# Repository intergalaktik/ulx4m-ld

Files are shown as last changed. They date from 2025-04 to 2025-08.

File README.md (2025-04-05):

# ULX4M-LD PCB

[ULX4M] = University digital Logic Learning Xtensible board release 4 Moduler successor of [ULX3S](http://radiona.org/ulx3s) = [University digital Logic](https://www.fer.unizg.hr/en/course/diglog) Learning
Xtensible board release 3 with SDRAM,
Successor of [ULX2S](http://github.com/emard/ulx2s).

3D preview

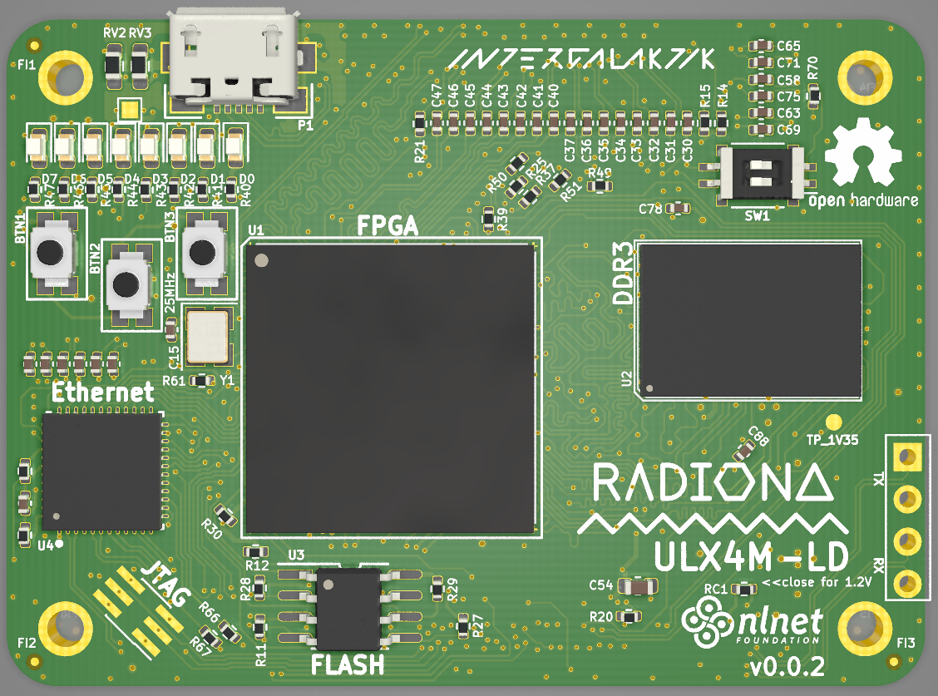
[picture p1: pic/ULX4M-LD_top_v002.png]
TOP

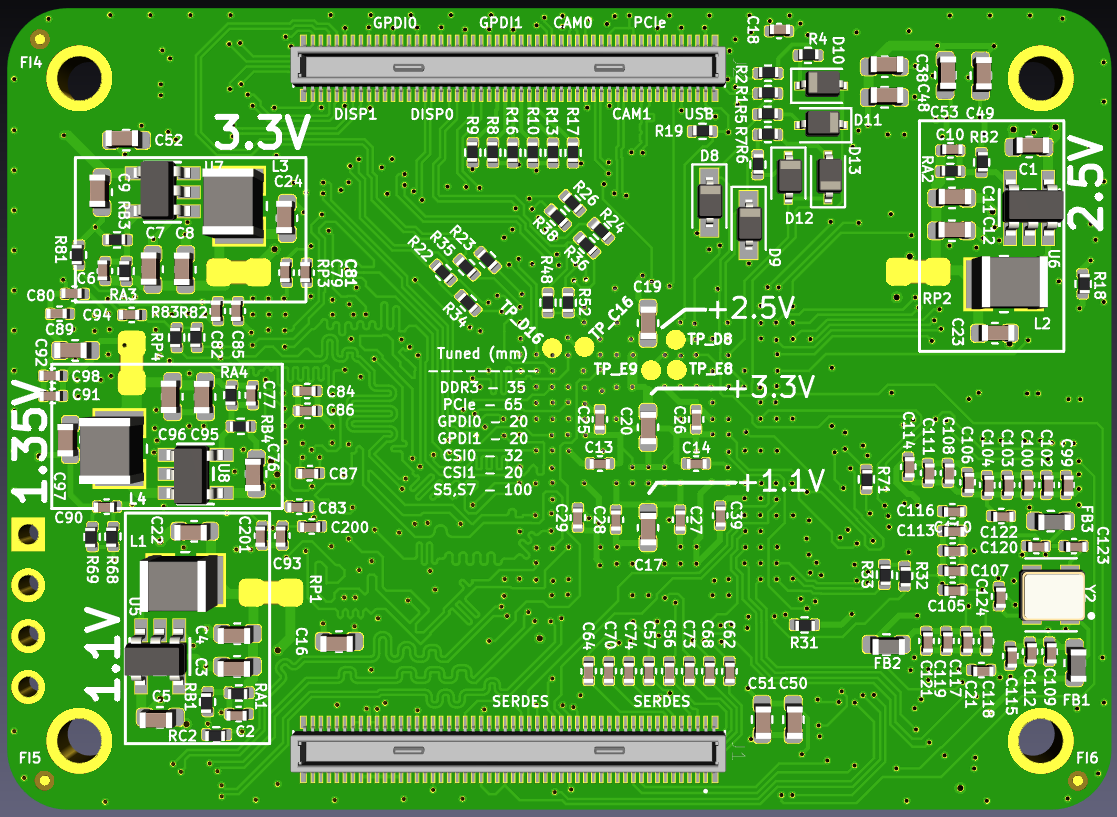
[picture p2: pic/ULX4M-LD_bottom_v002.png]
BOTTOM

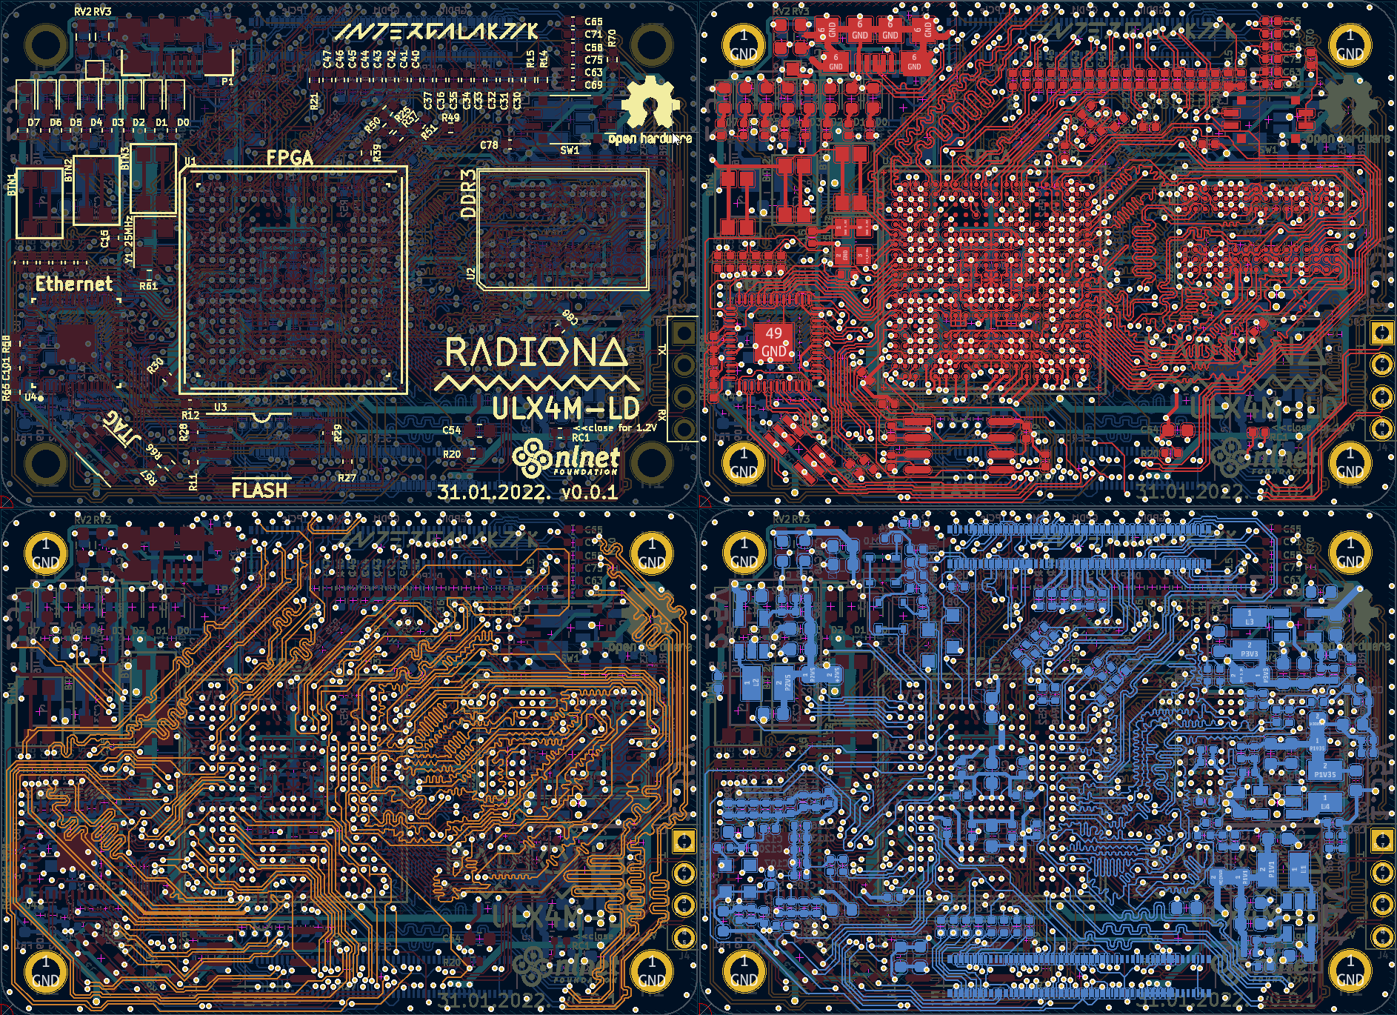
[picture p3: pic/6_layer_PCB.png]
Layers_v001


### Panel

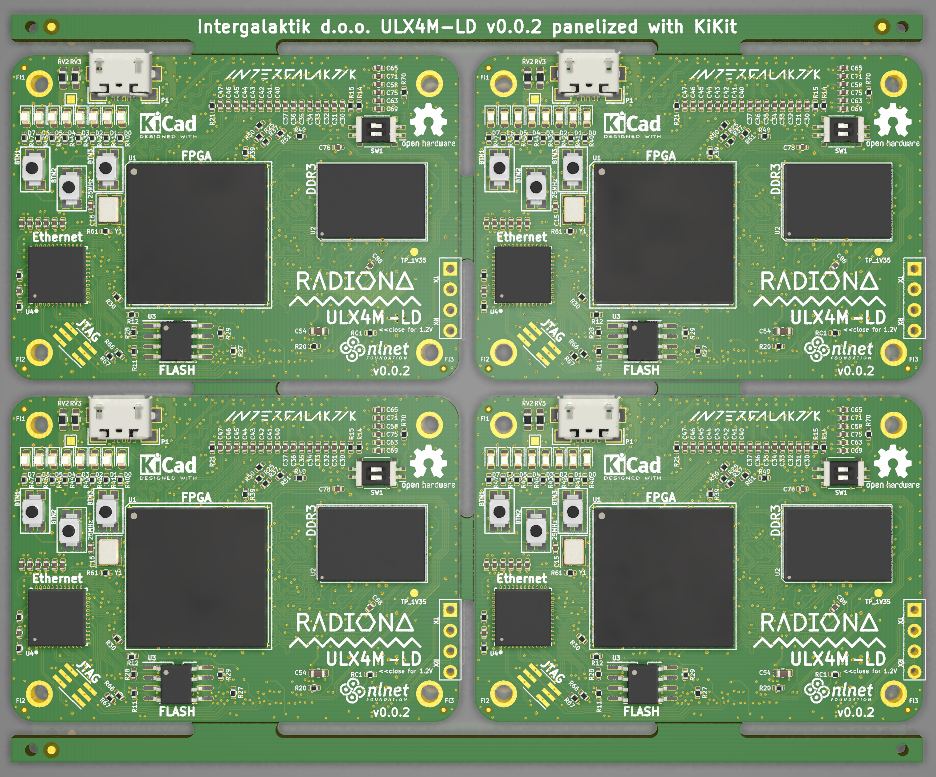
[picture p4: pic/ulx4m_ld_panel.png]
Panel


[Schematics](/doc/schematics.pdf) and PCB KiCAD 5 PCB editor:

    kicad ulx4m.pro

# Features

FPGA: Lattice ECP5 [LFE5U-85F-6BG381C](http://www.latticesemi.com/~/media/LatticeSemi/Documents/DataSheets/ECP5/FPGA-DS-02012.pdf?document_id=50461) (12/25/45/85K LUT)

### Main parts

LFE5UM-85F-8BG381C

MT41K256M16TW-107 512MB DDR3

W25Q128JVSIM NOR Flash spiFlash, 3V, 128M-bit, 4Kb Uniform Sector

Ethernet - KSZ9031RNXCA

### Programming options

External JTAG programming connector

JTAG connected to GPIO (programming with FTDI or ESP32)

USB (bootloader)

### Periferals

- [x] 2 lane CSI camera port  CAM0 and CAM1

- [x] 2 lane DSI display port DISP0 (fake differential)

- [x] SerDes pair connected to second DSI connector DISP1

- [x] SerDes pair (TX/RX) connected to 2.0 header (radio experiments)

- [x] True differential GPDI video output

- [x] Fake differential GPDI video output

- [x] SD card connection - shared with HAT pins

- [x] SerDes connected to PCIe 1x 

- [x] 2x SerDes pairs connected over capacitors to connector

- [x] GPIOs

- [x] 3 Buttons

- [x] 2 DIP SW

- [x] 8 LEDs

## References

https://github.com/gatecat/TrellisBoard

https://github.com/orangecrab-fpga/orangecrab-hardware

https://github.com/antmicro/ecp5-dc-scm

https://github.com/butterstick-fpga/butterstick-hardware

## Work on this board is financed by NLnet foundation

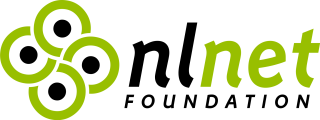
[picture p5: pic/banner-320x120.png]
NLnet


https://nlnet.nl/project/ULX3M/

## Check up our blogposts

https://intergalaktik.eu/news/ulx4s-v0-0-1

https://intergalaktik.eu/news/ulx4s-v0-0-2

https://intergalaktik.eu/news/blending-ulx4m-nlnet-funded-fpga-board

https://intergalaktik.eu/news/production-testing-automation-for-ulx3s

https://intergalaktik.eu/news/blending-ulx4m-ls-v002

## Contact us

Discord: https://discord.gg/qwMUk6W

Gitter: https://gitter.im/ulx3s/Lobby

Mail: warp@intergalaktik.eu

Twitter: https://twitter.com/intergalaktikEU

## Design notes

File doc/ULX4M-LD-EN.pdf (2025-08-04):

MANUAL FOR THE USE OF MODULAR TILES

# ULX4M-LD

1

SADRŽAJ

ULX4M-LD (Lattice+DDR3)

### 1. Introduction 1.1. Main parts 1.2. Programing options 1.3. Periferije 1.4. Electrical and mechanical specifications 1.5. Pinout 1.6. Power 2. ULX4M-LD description and instructions 3. ULX4M-LD on the internet 3.1. ULX4M-LD design files 3.2. ULX4M-LD v2 schematics

### 3.3. ULX4M-LD v2 LPF

### 3.4. ULX4M pohrana 4. JTAG over GPIO 5. DFU bootloader for ULX4M 5.1. Usage 5.2. Write Protecting Bootloader 6. Chat and support 6.1. Instructions for safe use

2

# ULX4M-LD (Lattice+DDR3)

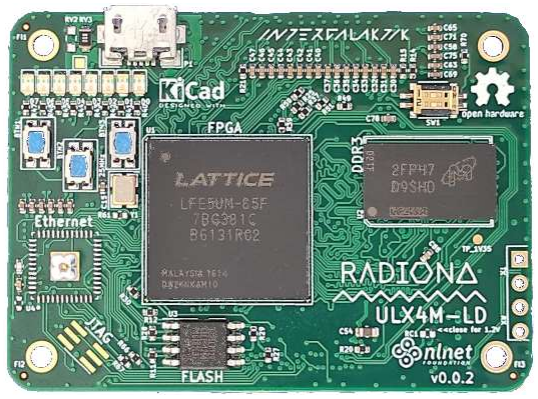
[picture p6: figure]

Slika 1. ULX4M-LD modular plate

FPGA: Lattice ECP5 LFE5U-85F-6BG381C (12/25/45/85K LUT)

3

# 1.Introduction

ULX4M-LD (Lattice + DDR3) is a system on a module (SoM) board that can be used on CM4 compatible base boards or as a standalone board.

## 1.1. Main parts

- LFE5UM-85F-8BG381C
- MT41K256M16TW-107 512MB DDR3
- W25Q128JVSIM NOR Flash spiFlash, 3V, 128M-bit, 4Kb Uniform Sector
- Ethernet – KSZ9031RNXCA

## 1.2. Programing options

External JTAG programming connector

JTAG connected to GPIO (programming with FTDI or ESP32)

USB (bootloader)

## 1.3. Periferije

- 2 lane CSI camera port CAM0 and CAM1
- 2 lane DSI display port DISP0 (fake differential)
- SerDes pair connected to second DSI connector DISP1
- SerDes pair (TX/RX) connected to 2.0 header (radio experiments)
- True differential GPDI video output
- Fake differential GPDI video output

4

- SD card connection - shared with HAT pins
- SerDes connected to PCIe 1x
- 2x SerDes pairs connected over capacitors to connector
- GPIOs
- 3 Buttons
- 2 DIP SW
- 8 LEDs

## 1.4. Electrical and mechanical specifications

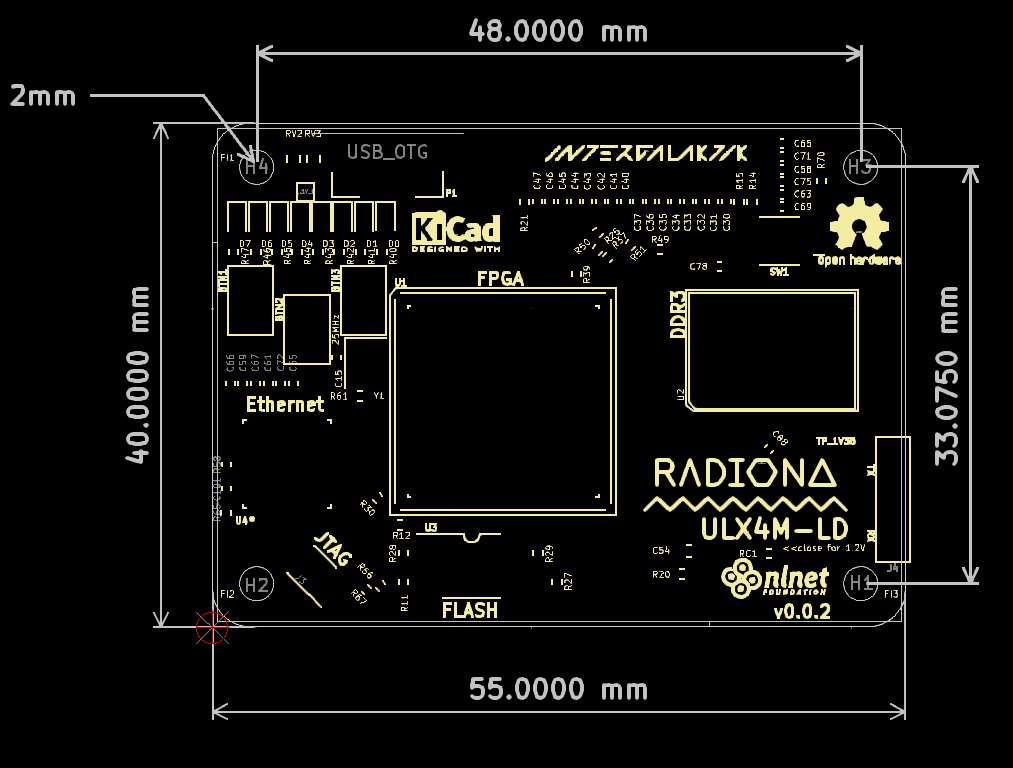
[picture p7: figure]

Slika 2. Electrical and mechanical specifications

5

## 1.5. Pinout

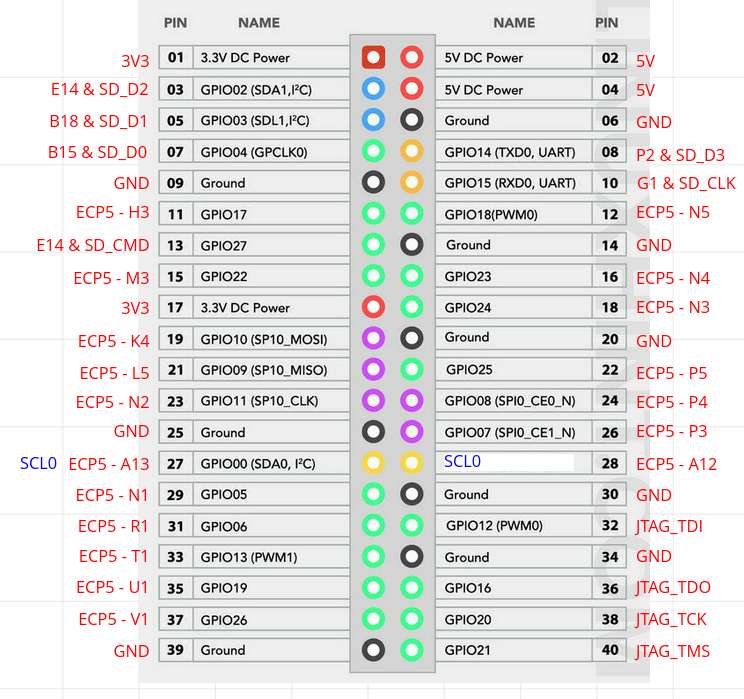
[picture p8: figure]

Slika 3. Input/output pins

## 1.6. Power

ULX4M requires at least 500mA to function safely. A 5V power supply can be provided over a USB port or over GPIO. 3.3V OUTPUT from ULX3S can handle up to 1A if appropriate input power is used.

6

# 2.ULX4M-LD description and instructions

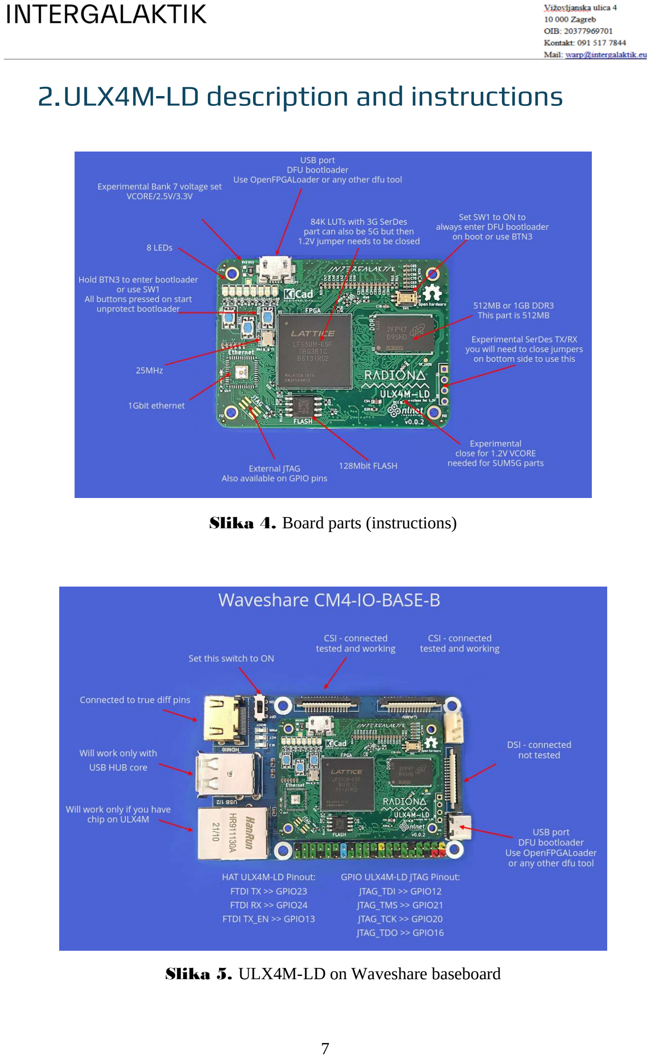
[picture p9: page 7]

Slika 4. Board parts (instructions)

Slika 5. ULX4M-LD on Waveshare baseboard

7

On this version SD_CARD is also connected to GPIO pins, so we can share it with ESP32 as on ULX3S.

On this version FPGA JTAG pins are connected to some GPIO pins so you will not be able to use them as GPIOs, but you can access JTAG over GPIO.

If a Waveshare IO board is used it can be powered from USB-C.

If you are using a Raspberry IO board then you will need 12V DC input as micro USB does not have 5V connected. There is one wire hack that can provide 5V from USB to the board. If this hack is used USB HOST will not work as it will disable HUB chip.

8

# 3.ULX4M-LD on the internet

## 3.1. ULX4M-LD design files

https://github.com/intergalaktik/ulx4m/tree/ulx4m-ls

## 3.2. ULX4M-LD v2 schematics

https://github.com/intergalaktik/ulx4m/blob/ulx4m-ld/doc/schematics.pdf

## 3.3. ULX4M-LD v2 LPF

https://github.com/intergalaktik/ulx4m/blob/ulx4m-ls/doc/constraints/prototype/ulx4m-ld_v002.lpf

## 3.4. ULX4M examples

https://github.com/lawrie/ulx4m_examples

https://github.com/lawrie/ulx4m_amaranth_examples

https://github.com/emard/ulx3s-misc

https://github.com/emard/had2019-playground/tree/master/projects/bootloader

https://github.com/goran-mahovlic/mipi-csi-2

https://github.com/hdl4fpga/hdl4fpga

9

# 4.DFU bootloader for ULX4M

USB DFU at US1 port for FPGA flashing. DFU is very fast.

Source is based on HAD2019 badge bootloader modified to ULX3S bootloader

Bootloader by default skips to the user's bitstream. If FLASH doesn't contain a valid user's bitstream, LEDs will blink because the bootloader is constantly restarting. This is normal.

To enter bootloader, hold BTN2 or set DIP SW1=ON and plug US1 In bootloader mode, LEDs 0-2 should be ON, other LEDs 3-7 OFF:

lsusb

Bus 001 Device 117: ID 1d50:614b OpenMoko, Inc. ULX4M-LD(DFU)

On linux, it's practical to add a udev rule which allows normal users members of "dialout" group to also run dfu-util, otherwise it should be run as root:

# file: /etc/udev/rules.d/80-fpga-dfu.rules

# this is for DFU 1d50:614b libusb access

ATTRS{idVendor}=="1d50", ATTRS{idProduct}=="614b", \

GROUP="dialout", MODE="666"

DFU is very fast, writes bitstreams in a few seconds.

## 4.1. Usage

To upload a user bitstream, hold BTN2 or turn on DIP SW1 and plug USB. Here are some commandline examples:

openFPGALoader -b ulx3s-dfu blink.bit

or

dfu-util -a 0 -D blink.bit

To exit the launcher and execute the user bitstream, use the

10

command DFU:
dfu-util -a 0 -e

To upgrade bootloader, hold BTN1 and BTN2 and plug USB:

## 4.2. Write Protecting Bootloader

To prevent accidental overwriting, flash chips have options to protect a range of address space.

16MB ISSI and Winbond FLASH chips are supported

Different FLASH chips have standard/compatible commands for reading and writing but different commands for write protection. On ULX3S usual 16MB chips are ISSI IS25LP128 or Winbond W25Q128, both are supported by esp32ecp5 and work.

4MB ISSI FLASH chip is not supported

ISSI IS25LP032 4MB is actually "supported", it has the same datasheet and commands as IS25LP128 but the onboard chip probably has some bug, it can't protect the address range where the bootloader is.

Protected range: first 2MB

For this bootloader, the first 2MB (address 0 - 0x1FFFFF) should be write protected. It contains a bootloader bitstream and some data structure that can jump to the user's bitstream which starts from 0x200000.

From what it protects

FLASH protection applied here is based on non-OTP bits so it's reversible and protects from accidental overwriting with "fujprog", "esp32ecp5" and DFU bootloader itself. "fujprog" will segfault early, "esp32ecp5" will stop after the first block verify, bootloader will upload data without error but content will not be written.

The current version of "openFPGALoader" will silently remove non-OTP write protection, overwrite the bootloader and leave the FLASH chip unprotected.

ISSI FLASH should be always safe and reversible. Winbond FLASH protection can set non-reversible OTP status register lock bit and in that case, there is no known way to remove protection.

11

# 5.Chat and support

Discord channel

- https://discord.gg/qwMUk6W (problems/question/general chat)

## 5.1. Instructions for safe use

This product shall be connected to a computer/laptop USB port or external power supply rated at 5V DC with maximum current of 2A. Any external power supply used with ULX4M shall comply with relevant regulations and standards applicable in the country of intended use. This product should be operated in a well ventilated environment and should not be covered.

This product should be placed on a stable, flat, non-conductive surface in use and should not be contacted by conductive items. The connection of unapproved devices to any receptacle may affect compliance or results in damage to the unit and invalidate the warranty.

Do not expose it to water, moisture or place on a conductive surface whilst in operation Do not expose it to heat from any source; ULX4M is designed for reliable operation at normal ambient room temperatures. Take care whilst handling to avoid mechanical or electrical damage to the printed circuit board and connectors. Avoid handling ULX4M while it is powered.

Only handled by the edges to minimize the risk of electrostatic discharge damage. All peripherals used with ULX4M should comply with relevant standards for the country of use and be marked accordingly to ensure that safety and performance requirements are met. ULX4M requires at least 500mA to function safely.

12

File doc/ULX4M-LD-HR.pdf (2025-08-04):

PRIRU NIK ZA KORIŠTENJE MODULARNIH PLO ICA Č | Č

# ULX4M-LD

1

SADRŽAJ

ULX4M-LD (Lattice+DDR3)

1. Uvod 1.1. Glavni dijelovi 1.2. Mogućnost programiranja 1.3. Periferije 1.4. Električne i mehaničke specifikacije 1.5. Pinout (ulazno/izlazni pinovi) 1.6. Snaga 2. ULX4M-LD opis i upute 3. ULX4M-LD na internetu 3.1. ULX4M-LD datoteke dizajna 3.2. ULX4M-LD v2 shematski prikazi 3.3. ULX4M pohrana 4. JTAG over GPIO 5. DFU pokretački program za ULX4M 5.1. Korištenje 5.2. Bootloader za zaštitu od pisanja 6. Chat i podrška 6.1. Upute za sigurnosnu upotrebu

2

# ULX4M-LD (Lattice+DDR3)


Slika 1. ULX4M-LD modularna pločica

FPGA: Lattice ECP5 LFE5U-85F-6BG381C (12/25/45/85K LUT)

3

# 1.Uvod

ULX4M-LD (Lattice + DDR3) je sustav na ploči modula (SoM) koji se može koristiti na CM4 kompatibilnoj osnovnoj ploči ili kao samostalna ploča.

## 1.1. Glavni dijelovi

- LFE5UM-85F-8BG381C
- MT41K256M16TW-107 512MB DDR3
- W25Q128JVSIM NOR Flash spiFlash, 3V, 128M-bit, 4Kb Uniform Sector
- Ethernet – KSZ9031RNXCA

## 1.2. Mogućnost programiranja

Vanjski JTAG konektor za programiranje, JTAG spojen na GPIO (programiranje s FTDI ili ESP32) i USB (bootloader).

## 1.3. Periferije

- Priključak CSI kamere s dvije trake CAM0 i CAM1,
- Dva traka DSI zaslonski priključak DISP0 (lažni diferencijal),
- SerDes par spojen je na drugi DSI konektor DISP1,
- SerDes par (TX/RX) spojen na 2.0 zaglavlje (radio eksperimenti),
- Pravi diferencijalni GDPI video izlaz,
- Lažni diferencijalni GDPI video izlaz,

4

- Veza SD krtice – dijeli se s HAT pinovima,
- SerDes spojen na PCIe 1x,
- 2x SerDes para spojena preko kondenzatora na konektor,
- GPIOs,
- Tri gumba,
- 2 DIP SW,
- 8 LEDs.

## 1.4. Električne i mehaničke specifikacije


Slika 2. Električne i mehaničke specifikacije

5

## 1.5. Pinout (ulazno/izlazni pinovi)


Slika 3. Ulazno/izlazni pinovi

## 1.6. Snaga

ULX4M zahtijeva najmanje 500 Ma za siguran rad. Napajanje od 5V može se osigurati preko USB priključka ili preko GPIO. 3,3V IZLAZ iz ULX3S može podnijeti do 1A ako se koristi odgovarajuća ulazna snaga.

6

# 2.ULX4M-LD opis i upute

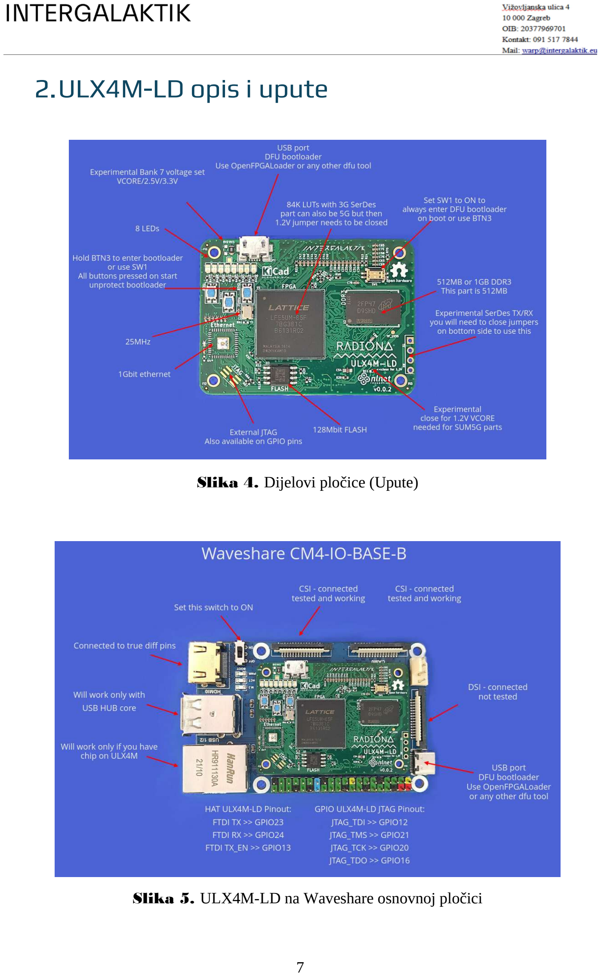
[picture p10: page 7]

Slika 4. Dijelovi pločice (Upute)

Slika 5. ULX4M-LD na Waveshare osnovnoj pločici

7

Na ovoj verziji SD kartica je također spojena na GPIO pinove, tako da je možemo dijeliti s ESP32 kao na ULX3S.

Na ovoj verziji FPGA JTAG pinovi povezani su s nekim GPIO pinovima tako da ih nećete moći koristiti kao GPIO, ali možete pristupiti JTAG-u preko GPIO-a.

Ako se koristi Waveshare IO ploča, može se napajati s USB-C.

Ako koristite Raspberry IO ploču, trebati će Vam 12V DC ulaz jer mikro USB nema priključenih 5V. Postoji jedna žica koja može osigurati 5V od USB-a do ploče. Ako se koristi ovaj hack, USB HOST neće raditi jer će onemogućiti HUB čip.

8

# 3.ULX4M-LD na internetu

## 3.1. ULX4M-LD datoteke dizajna

https://github.com/intergalaktik/ulx4m/tree/ulx4m-ls

## 3.2. ULX4M-LD v2 shematski prikazi

https://github.com/intergalaktik/ulx4m/blob/ulx4m-ld/doc/schematics.pdf

## 3.3. ULX4M-LD v2 LPF

https://github.com/intergalaktik/ulx4m/blob/ulx4m-ls/doc/constraints/prototype/ulx4m-ld_v002.lpf

## 3.4. ULX4M primjeri

https://github.com/lawrie/ulx4m_examples

https://github.com/lawrie/ulx4m_amaranth_examples

https://github.com/emard/ulx3s-misc

https://github.com/emard/had2019-playground/tree/master/projects/bootloader

https://github.com/goran-mahovlic/mipi-csi-2

https://github.com/hdl4fpga/hdl4fpga

9

# 4.DFU pokretački program za ULX4M

USB DFU na US1 priključku za FPGA bljeskanje, DFU je vrlo brz.

Izvor se temelji na HAD2019 badge bootloader modificiranom u ULX3S bootloaderu.

Bootloader prema zadanim postavkama preskače na koristiv bitstream. Ako FLASH ne sadrži važeći korisnički bitstream, LED će treptati jer se bootloader stalno ponovno pokreće. Ovo je normalno.
Za ulazak u bootloader, držite BTN2 ili postavite DIP SW1=ON i priključite US1. U bootloader modu, LED 0-2 bi trebali biti UKLJUČENI, ostali LED 3-7 ISKLJUČENI:

Bus 001 Device 117: ID 1d50:614b OpenMoko, Inc. ULX4M-LD(DFU).
Na linuxu je praktično dodati udev pravilo koje omogućuje korisnicima i članovima "dialout" grupe da također pokreću dfu-util, inače bi ga trebalo pokrenuti kao root:
# file: /etc/udev/rules.d/80-fpga-dfu.rules

# this is for DFU 1d50:614b libusb access

ATTRS{idVendor}=="1d50", ATTRS{idProduct}=="614b", \ GROUP="dialout", MODE="666"
DFU je vrlo brz, zapisuje bitstream u nekoliko sekundi.

## 4.1. Korištenje

Za prijenos korisničkog bitstreama, držite BTN2 ili uključite DIP SW1 i uključite USB. Evo nekoliko primjera naredbenog retka:
openFPGALoader -b ulx3s-dfu blink.bit

ili

dfu-util -a 0 -D blink.bit

Da biste izašli iz pokretačkog programa i izvršili korisnički bitstream, upotrijebite

naredbu DFU:
dfu-util -a 0 -e
Za nadogradnju bootloadera, držite BTN1 i BTN2 i uključite USB.

10

## 4.2. Bootloader za zaštitu od pisanja

Kako bi se spriječilo slučajno prepisivanje FLASH čipovi imaju opcije za zaštitu raspona adresnog prostora. Podržani su 16MB ISSI i Winbond FLASH čipovi.
Različiti FLASH čipovi imaju standardne/kompatibilne naredbe za čitanje i pisanje, ali različite naredbe za zaštitu od pisanja.

4MB ISSI FLASH čip nije podržan.

ISSI IS25LP032 4MB je zapravo podržan, ima istu podatkovnu tablicu i naredbe kao IS25LP128, ali ugrađeni čip vjerojatno ima neku grešku, ne može zaštititi raspon adresa gdje je bootloader. Zaštićeni raspon: prva dva MB.

Za ovaj bootloader, prvih 2MB (adresa 0 - 0x1FFFFF) treba biti zaštićeno od pisanja. Sadrži bitstream bootloadera i neke podatkovne strukture koje mogu skočiti na korisnički bitstream koji počinje od 0x200000. Od onoga što štiti.

Ovdje primijenjena FLASH zaštita temelji se na bitovima koji nisu OTP pa je reverzibilna i štiti od slučajnog prepisivanja s "fujprog", "esp32ecp5" i samim DFU bootloaderom. "Fujprog" će rano pokrenuti segfault, "esp32ecp5" će se zaustaviti nakon prve provjere bloka, bootloader će učitati podatke bez pogreške, ali sadržaj neće biti upisan.

Trenutna verzija "openFPGALoader" će tiho ukloniti ne-OTP zaštitu od pisanja, prebrisati bootloader i ostaviti FLASH čip nezaštićenim.

ISSI FLASH treba uvijek biti siguran i reverzibilan. Winbond FLASH zaštita može postaviti nepovratni bit zaključavanja registra statusa OTP i u tom slučaju ne postoji poznati način za uklanjanje zaštite.

11

# 5.Chat i podrška

Discord channel

- https://discord.gg/qwMUk6W (problems/question/general chat)

## 5.1. Upute za sigurnosnu upotrebu

Ovaj proizvod mora biti spojen na USB priključak računala/prijenosnog računala ili vanjsko napajanje nazivno na 5 V DC s maksimalnom strujom od 2 A. Svako vanjsko napajanje koje se koristi s ULX4M mora biti u skladu s relevantnim propisima i standardima primjenjivim u zemlji namjeravane uporabe.

Ovaj proizvod treba raditi u dobro prozračenom okruženju i ne smije biti pokriven. Ovaj proizvod tijekom uporabe treba postaviti na stabilnu, ravnu površinu koja nije vodljiva i ne smije ga dodirivati vodljivi predmeti. Spajanje neodobrenih uređaja na bilo koju utičnicu može utjecati na sukladnost ili rezultirati oštećenjem jedinice i poništiti jamstvo.

Nemojte ga izlagati vodi, vlazi niti ga stavljati na vodljivu površinu dok radi. Nemojte ga izlagati toplini iz bilo kojeg izvora; ULX4M je dizajniran za pouzdan rad pri normalnim sobnim temperaturama.

Pazite tijekom rukovanja kako biste izbjegli mehanička ili električna oštećenja tiskane ploče i konektora. Izbjegavajte rukovanje ULX4M dok je napajan. Držite samo za rubove kako biste smanjili rizik od oštećenja elektrostatičkim pražnjenjem.

Svi periferni uređaji koji se koriste s ULX4M trebaju biti u skladu s relevantnim standardima za zemlju upotrebe i biti odgovarajuće označeni kako bi se osiguralo ispunjavanje sigurnosnih i radnih zahtjeva. ULX4M zahtijeva najmanje 500 mA za siguran rad.

12

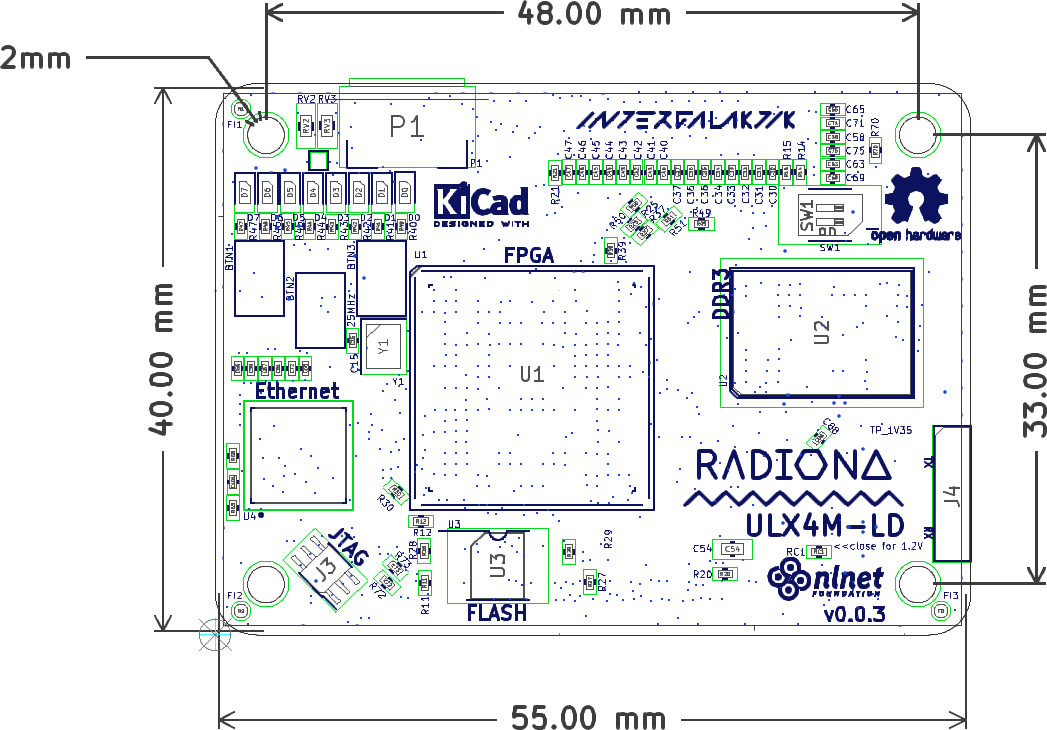
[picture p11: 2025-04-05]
pic/ulx4m_drawings.png

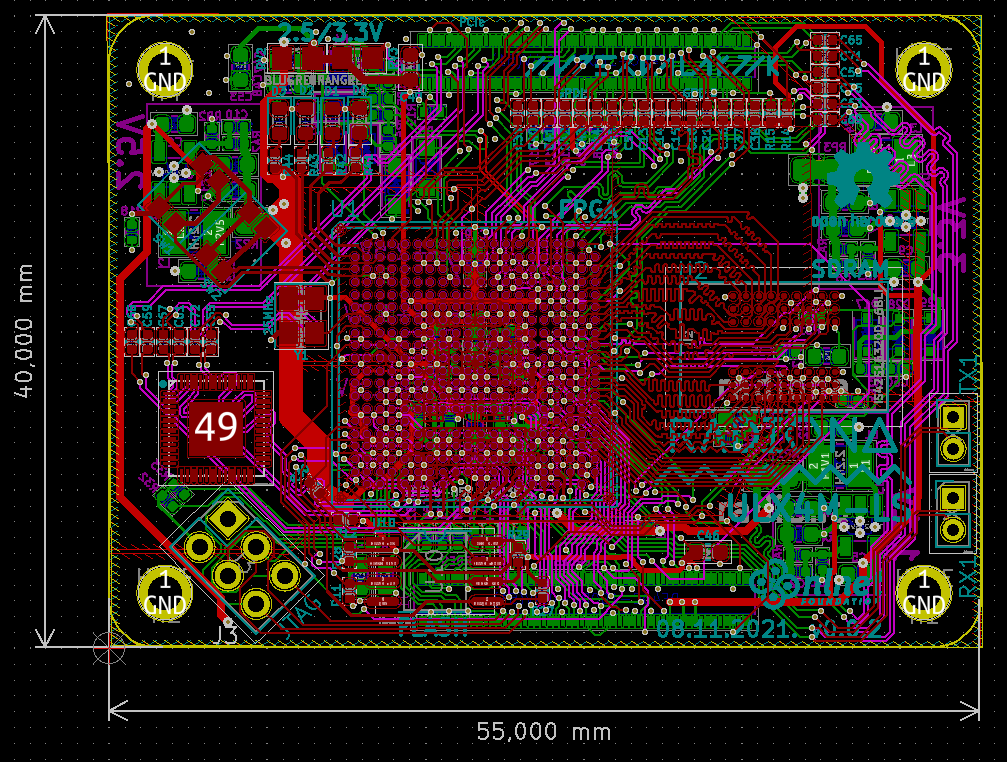
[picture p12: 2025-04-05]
pic/ULX4M_routed_V002.png

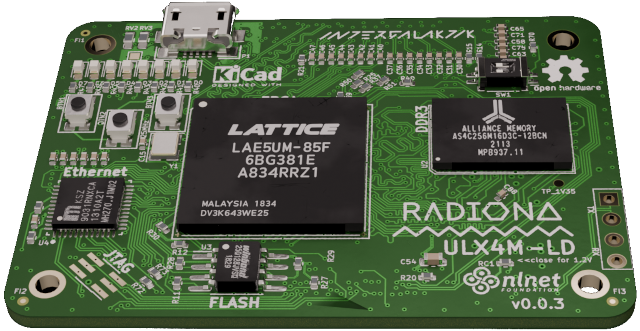
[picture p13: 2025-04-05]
pic/Blender_ULX4M-LD-003-low-ress.png

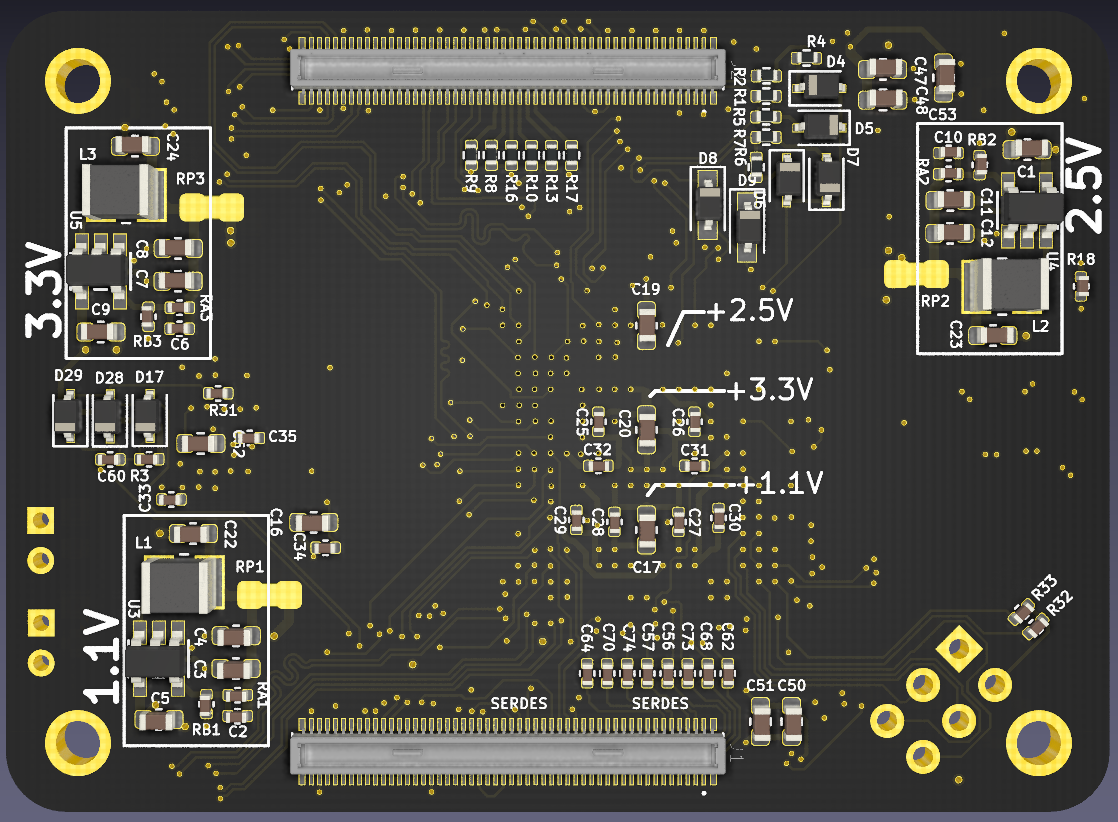
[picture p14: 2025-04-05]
pic/ULX4M_bottom_v002.png

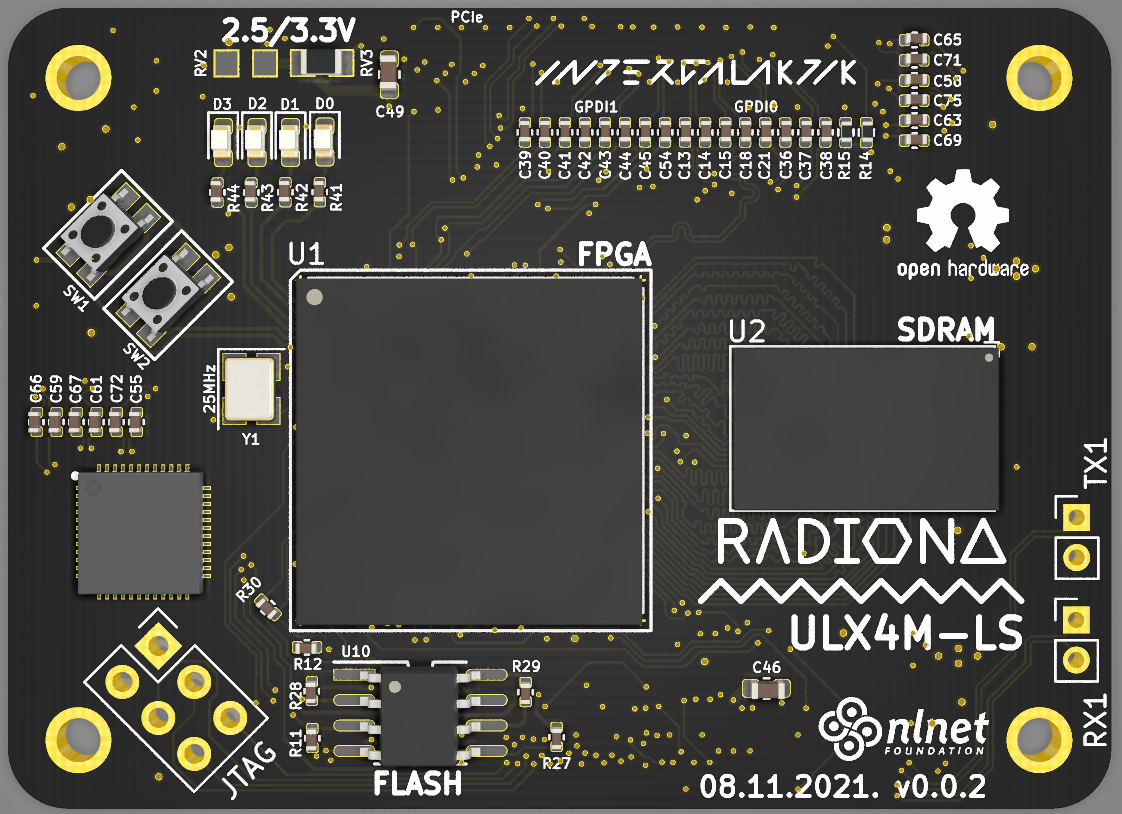
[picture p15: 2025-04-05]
pic/ULX4M_top_v002.png

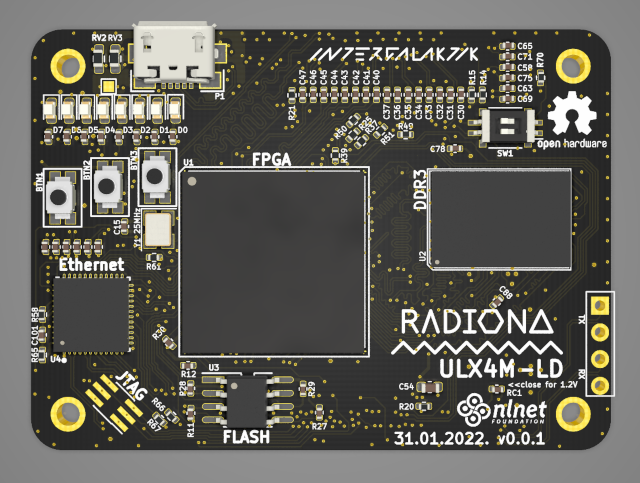
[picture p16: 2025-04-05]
pic/ULX4M-LD_top_v001.png

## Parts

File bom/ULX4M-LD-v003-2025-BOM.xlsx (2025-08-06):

Original Part | Original Manufacturer | Reference | Quantity | Part Match | Description | Selected Offers | Selected Distributor | Selected Distributor SKU | Selected Offers (Distributor Link) | Stock | Unit Price | Total Quantity | Total Price | Matched Part Number | Matched Manufacturer | Packaging | Min | Mult | Total | Arrow Electronics | Avnet | DigiKey | Future Electronics | Mouser | Newark | RS | Manufacturer Lifecycle | RoHS | REACH | Datasheets | Subtotal | Stock
LTST-C190KRKT | Lite-On | D0, D4 | 2 | Exact | LED LTST-C190KRKT; SMD 0603; czerwona 631-639nm; 99mcd /20mA; water clear | Mouser 859-LTST-C190KRKT (https://octopart.com/opatz8j6/a1) | Mouser | 859-LTST-C190KRKT (https://octopart.com/opatz8j6/a1) | https://octopart.com/opatz8j6/a1 | 290440 | 0.14 | 2 | 0.28 | LTST-C190KRKT | Lite-On | Cut Tape | 1 |  | €11.82 (qty: 200) | LTST-C190KRKT | LTST-C190KRKT | 160-1436-1-ND | 5050042 |  |  | 6920981 | Active | Compliant | Yes | Upverter: https://datasheet.octopart.com/LTST-C190KRKT-Lite-On-datasheet-32047000.pdf | 11.82 | 12041
DFE322520F-2R2M=P2 | Murata | L1, L2, L3, L4 | 4 | Selected | Inductor Chip Shielded Wirewound 2.2uH 20% 1MHz Metal Alloy 3.3A 1210 Emboss T/R | Mouser 81-DFE322520F2R2M=P2 (https://octopart.com/opatz8j6/a1) | Mouser | 81-DFE322520F2R2M=P2 (https://octopart.com/opatz8j6/a1) | https://octopart.com/opatz8j6/a1 | 604 | 0.57 | 4 | 2.28 | DFE322520F-2R2M=P2 | Murata |  | 1 | 1 | €48.80 (qty: 400) | BLM21SP181SH1D |  | 490-18585-1-ND |  | 81-BLM21SP181SH1D | 65AC5848 |  | Active | Compliant | Yes | IHS: https://datasheet.octopart.com/BLM21SP181SH1D-Murata-datasheet-180807131.pdf | 48.8 | 1835
LTST-C190TBKT | Lite-On | D3, D7 | 2 | Exact | OPTOELECTRONICS - SMD Chip LED - TopView Single Color Chip LED, Blue, 470 at 20mA, 28 to approx. 180 at 20mA | Mouser 859-LTST-C190TBKT (https://octopart.com/opatz8j6/a1) | Mouser | 859-LTST-C190TBKT (https://octopart.com/opatz8j6/a1) | https://octopart.com/opatz8j6/a1 | 40842 | 0.25 | 2 | 0.5 | LTST-C190TBKT | Lite-On |  | 1 | 1 | €14.68 (qty: 200) |  |  | 160-1646-1-ND | 4438875 |  |  | 6920994 | Active | Compliant | Yes | Upverter: https://datasheet.octopart.com/LTST-C190TBKT-Lite-On-datasheet-26684744.pdf | 14.68 | 18883
LTST-C190KAKT | Lite-On | D1, D5 | 2 | Exact | Single Color LED, Red Orange, Water Clear, 1.06mm | Mouser 859-LTST-C190KAKT (https://octopart.com/opatz8j6/a1) | Mouser | 859-LTST-C190KAKT (https://octopart.com/opatz8j6/a1) | https://octopart.com/opatz8j6/a1 | 9575 | 0.2 | 2 | 0.4 | LTST-C190KAKT | Lite-On | Cut Tape | 1 |  | €25.00 (qty: 200) | LTST-C190KAKT |  | 160-1433-1-ND |  |  |  |  | Active | Compliant | Yes | IHS: https://datasheet.octopart.com/LTST-C190KAKT-Lite-On-datasheet-180605177.pdf | 25 | 47325
LTST-C191KGKT | Lite-On | D2, D6 | 2 | Exact | Single Color LED, Ultra Bright Green, Water Clear, 1.1mm | Mouser 859-LTST-C191KGKT (https://octopart.com/opatz8j6/a1) | Mouser | 859-LTST-C191KGKT (https://octopart.com/opatz8j6/a1) | https://octopart.com/opatz8j6/a1 | 185723 | 0.15 | 2 | 0.3 | LTST-C191KGKT | Lite-On |  | 1 | 1 | €8.66 (qty: 200) | LTST-C191KGKT |  | 160-1446-1-ND | 3023739 |  |  | 6921010 | Active | Compliant | Yes | Electro Sonic: https://datasheet.octopart.com/LTST-C191KGKT-Lite-On-datasheet-86397321.pdf | 8.66 | 6081
BZT52C3V6S-TP | MCC | D8, D9 | 2 | Exact | Zener Diode, 3.6V V(Z), 5.56%, 0.2W, Silicon, Unidirectional | Mouser 833-BZT52C3V6S-TP (https://octopart.com/opatz8j6/a1) | Mouser | 833-BZT52C3V6S-TP (https://octopart.com/opatz8j6/a1) | https://octopart.com/opatz8j6/a1 | 1313 | 0.28 | 2 | 0.56 | BZT52C3V6S-TP | MCC | Tape & Reel | 1 |  | €13.85 (qty: 200) | BZT52C3V6S-TP |  | BZT52C3V6S-TPMSCT-ND |  | 833-BZT52C3V6S-TP |  |  | Active | Compliant | Yes | Future Electronics: https://datasheet.octopart.com/BZT52C3V6S-TP-MCC-datasheet-135782124.pdf | 13.85 | 1313
TLV62569DBVR | Texas Instruments | U5, U6, U7, U8 | 4 | Exact | IC REG BUCK ADJ 2A SOT23-5 "Buck Switching Regulator IC Positive Adjustable 0.6V Output 2A SC-74A, SOT-753" | Arrow Electronics TLV62569DBVR (https://octopart.com/opatz8j6/a1) | Arrow Electronics | TLV62569DBVR (https://octopart.com/opatz8j6/a1) | https://octopart.com/opatz8j6/a1 | 102 | 0.2145 | 4 | 0.858 | TLV62569DBVR | Texas Instruments | Cut Tape | 1 |  | €38.11 (qty: 400) | TLV62569DBVR |  | 296-47360-1-ND |  | 595-TLV62569DBVR |  |  | Active | Compliant |  | Texas Instruments: https://octopart.com/opatz8j6/c1 | 38.11 | 12574
LFE5UM-85F-8BG381I | Lattice Semiconductor | U1 | 1 | Exact | FPGA LatticeECP5 Family 84000 Cells 40nm Technology 1.1V 381-Pin CABGA Tray | Arrow Electronics LFE5UM-85F-8BG381I (https://octopart.com/opatz8j6/a1) | Arrow Electronics | LFE5UM-85F-8BG381I (https://octopart.com/opatz8j6/a1) | https://octopart.com/opatz8j6/a1 | 180 | 103.43 | 1 | 103.43 | LFE5UM-85F-8BG381I | Lattice Semiconductor |  | 1 |  | €7970.38 (qty: 100) | LFE5UM-85F-8BG381I |  | LFE5UM-85F-8BG381I-ND |  | 842-LFE5UM85F8BG381I |  |  | Active | Compliant | Yes | IHS: https://datasheet.octopart.com/LFE5UM-85F-8BG381I-Lattice-Semiconductor-datasheet-180556152.pdf | 7970.38 | 208
AS4C512M16D3LB-12BCN | Alliance Memory | U2 | 1 | Exact | R-PBGA-B96 Surface Mount Tray 512MX16 ic memory 800MHz 20ns 9mm 8589934592bit | Newark 82AK3816 (https://octopart.com/opatz8j6/a1) | Newark | 82AK3816 (https://octopart.com/opatz8j6/a1) | https://octopart.com/opatz8j6/a1 | 84 | 27.13 | 1 | 27.13 | AS4C512M16D3LB-12BCN | Alliance Memory | Tray | 1 |  | €2185.50 (qty: 100) |  | AS4C512M16D3LB-12BCN |  |  | 913-4C51216D3LB12BCN | 82AK3816 |  | Active | Compliant | Yes | IHS: https://datasheet.octopart.com/AS4C512M16D3LB-12BCN-Alliance-Memory-datasheet-182231666.pdf | 2185.5 | 792
IS25LP128F-JBLE | ISSI | U3 | 1 | Exact | NOR Flash Serial (SPI, Dual SPI, Quad SPI) 2.5V/3V/3.3V 128M-bit 16M x 8 8ns 8-Pin SOIC | Arrow Electronics IS25LP128F-JBLE (https://octopart.com/opatz8j6/a1) | Arrow Electronics | IS25LP128F-JBLE (https://octopart.com/opatz8j6/a1) | https://octopart.com/opatz8j6/a1 | 745 | 1.79 | 1 | 1.79 | IS25LP128F-JBLE | ISSI |  | 1 | 1 | €146.85 (qty: 100) | IS25LP128F-JBLE | 38AC3510 |  |  | 870-IS25LP128F-JBLE |  |  | Active | Compliant | Yes | IHS: https://datasheet.octopart.com/IS25LP128F-JBLE-ISSI-datasheet-180100963.pdf | 146.85 | 3240
KSZ9031RNXCA-TR | Microchip | U4 | 1 | Exact | IC TRANSCEIVER FULL 4/4 48QFN 4/4 Transceiver Full Ethernet 48-QFN (7x7) | Mouser 998-KSZ9031RNXCATR (https://octopart.com/opatz8j6/a1) | Mouser | 998-KSZ9031RNXCATR (https://octopart.com/opatz8j6/a1) | https://octopart.com/opatz8j6/a1 | 8619 | 5.88 | 1 | 5.88 | KSZ9031RNXCA-TR | Microchip |  | 1 | 1 | €41.36 (qty: 13) | KSZ9031RNXCA-TR |  | KSZ9031RNXCA-CT-ND | 7025411 | 998-KSZ9031RNXCATR |  |  | Active | Compliant |  | Microchip: https://datasheet.octopart.com/KSZ9031RNXCA-TR-Microchip-datasheet-101587942.pdf | 41.36 | 13
ECS-2333-250-BN-TR | ECS International | Y1 | 2 | Exact | Series ESC-2333 3.3V 15pF -40°C~+85°C ±50ppm SMD/SMT Standard Clock Oscillators | Arrow Electronics ECS-2333-250-BN-TR (https://octopart.com/opatz8j6/a1) | Arrow Electronics | ECS-2333-250-BN-TR (https://octopart.com/opatz8j6/a1) | https://octopart.com/opatz8j6/a1 | 11481 | 0.6346 | 2 | 1.27 | ECS-2333-250-BN-TR | ECS International | Tape & Reel | 1 |  | €123.71 (qty: 200) | ECS-2333-250-BN-TR | ECS-2333-250-BN-TR | XC3035CT-ND |  | 520-2333-250-BNT | 79AK9042 |  | Active | Compliant | Yes | IHS: https://datasheet.octopart.com/ECS-2333-250-BN-TR-ECS-International-datasheet-164278824.pdf | 123.71 | 2724
CVS-02TB | Nidec Copal | SW1 | 1 | Exact | Switch DIP OFF ON SPST 2 Raised Slide 0.025A 24VDC Gull Wing SMD T/R | Mouser 229-CVS-02TB (https://octopart.com/opatz8j6/a1) | Mouser | 229-CVS-02TB (https://octopart.com/opatz8j6/a1) | https://octopart.com/opatz8j6/a1 | 34 | 3.05 | 1 | 3.05 | CVS-02TB | Nidec Copal | Tape & Reel | 1 |  | €193.13 (qty: 100) |  |  | 563-1193-1-ND |  | 229-CVS-02TB | 56AC5330 |  | Active | Compliant | Yes | IHS: https://datasheet.octopart.com/CVS-02TB-Nidec-Copal-datasheet-180925904.pdf | 193.13 | 359
EVPAA302K | Panasonic | BTN1, BTN2, BTN3 | 3 | Exact | Switch Tactile N.O. SPST Rectangular Button J-Bend 0.02A 15VDC 1.6N SMD Embossed T/R | Mouser 667-EVP-AA302K (https://octopart.com/opatz8j6/a1) | Mouser | 667-EVP-AA302K (https://octopart.com/opatz8j6/a1) | https://octopart.com/opatz8j6/a1 | 11103 | 0.84 | 3 | 2.52 | EVPAA302K | Panasonic | Cut Tape | 1 | 1 | €110.41 (qty: 300) |  |  |  |  |  | 47AC4938 |  | Active | Compliant | Yes | IHS: https://datasheet.octopart.com/EVPAA302K-Panasonic-datasheet-156880147.pdf | 110.41 | 422
BLM18PG121SN1D | Murata | FB1, FB2, FB3 | 3 | Exact | Ferrite Beads Multi-Layer 120Ohm 25% 100MHz 2A 50mOhm DCR 0603 Paper T/R | Mouser 81-BLM18PG121SN1D (https://octopart.com/opatz8j6/a1) | Mouser | 81-BLM18PG121SN1D (https://octopart.com/opatz8j6/a1) | https://octopart.com/opatz8j6/a1 | 259099 | 0.1 | 3 | 0.3 | BLM18PG121SN1D | Murata |  | 1 | 1 | €6.66 (qty: 300) | BLM18PG121SN1D | BLM18PG121SN1D | 490-1037-1-ND | 8156358 | 81-BLM18PG121SN1D | 73M9109 | 7241380 | Active | Compliant | Yes | IHS: https://datasheet.octopart.com/BLM18PG121SN1D-Murata-datasheet-180806579.pdf | 6.66 | 85520
DF40C-100DP-0.4V(51) | HIROSE ELECTRIC | J1, J2 | 2 | Exact | Conn Board to Board HDR 100 POS 0.4mm Solder ST Top Entry SMD T/R | Newark 65AK9728 (https://octopart.com/opatz8j6/a1) | Newark | 65AK9728 (https://octopart.com/opatz8j6/a1) | https://octopart.com/opatz8j6/a1 | 1924 | 1.2 | 2 | 2.4 | DF40C-100DP-0.4V(51) | HIROSE ELECTRIC |  | 1 | 1 | €214.00 (qty: 200) |  | DF40C-100DP-0.4V(51) | H11614CT-ND |  | 798-DF40C100DP0.4V51 |  |  | Active | Compliant | Yes | IHS: https://datasheet.octopart.com/DF40C-100DP-0.4V%2851%29-HIROSE-ELECTRIC-datasheet-166788320.pdf | 214 | 2183
10118192-0001LF | Amphenol Communications Solutions | P1 | 1 | Exact | Usb Connector, 5 Contact(S), Female, Right Angle, Surface Mount Terminal, Locking, Receptacle | DigiKey 609-4613-1-ND (https://octopart.com/opatz8j6/a1) | DigiKey | 609-4613-1-ND (https://octopart.com/opatz8j6/a1) | https://octopart.com/opatz8j6/a1 | 21605 | 0.43 | 1 | 0.43 | 10118192-0001LF | Amphenol Communications Solutions |  | 1 | 1 | €19.20 (qty: 100) | 10118192-0001LF | 67T2258 | 609-4613-1-ND |  | 649-10118192-0001LF | 67T2258 | 1822981 | Active | Compliant | Yes | Electro Sonic: https://datasheet.octopart.com/10118192-0001LF-Amphenol-Communications-Solutions-datasheet-55953129.pdf | 19.2 | 1093
1N914BWS | onsemi | D10, D11, D12, D13, D29 | 5 | Exact | Diode Ultra Fast Recovery Rectifier 75V 0.15A 2-Pin SOD-323F T/R | Newark 18X9969 (https://octopart.com/opatz8j6/a1) | Newark | 18X9969 (https://octopart.com/opatz8j6/a1) | https://octopart.com/opatz8j6/a1 | 8473 | 0.023 | 5 | 0.115 | 1N914BWS | onsemi |  | 1 | 1 | €16.25 (qty: 500) | 1N914BWS | 1N914BWS | 1N914BWSCT-ND | 4190584 | 512-1N914BWS | 18X9969 |  | Active | Compliant | Yes | Upverter: https://datasheet.octopart.com/1N914BWS-ON-Semiconductor-datasheet-11741836.pdf | 16.25 | 2230
GRM155R60J223KA01D | Murata | C13, C14, C15, C18, C21, C25, C26, C27, C28, C29, C39, C55, C56, C57, C58, C59, C61, C62, C63, C64, C65, C66, C67, C68, C69, C70, C71, C72, C73, C74, C75 | 31 | Exact | 0402 22 nF 6.3 V ±10% Tolerance X5R SMT Multilayer Ceramic Capacitor | Arrow Electronics GRM155R60J223KA01D (https://octopart.com/opatz8j6/a1) | Arrow Electronics | GRM155R60J223KA01D (https://octopart.com/opatz8j6/a1) | https://octopart.com/opatz8j6/a1 | 369 | 0.0008 | 31 | 0.0248 | GRM155R60J223KA01D | Murata | Cut Tape | 1 | 1 | €0.43701 (qty: 369) | GRM155R60J223KA01D |  |  |  | 81-GRM155R60J223KA1D | 97AK4044 |  | Not Recommended for New Designs | Compliant | Yes | TME: https://datasheet.octopart.com/GRM155R60J223KA01D-Murata-datasheet-165579666.pdf | 0.43701 | 369
GRM152R60J104KE19D | Murata | C30, C31, C32, C33, C34, C35, C36, C37, C40, C41, C42, C43, C44, C45, C46, C47, C88, C93, C94, C101, C122 | 21 | Exact | Ceramic Capacitor, Multilayer, Ceramic, 6.3V, 10% +Tol, 10% -Tol, X5R, 15% TC, 0.1uF, Surface Mount, 0402 | Arrow Electronics GRM152R60J104KE19D (https://octopart.com/opatz8j6/a1) | Arrow Electronics | GRM152R60J104KE19D (https://octopart.com/opatz8j6/a1) | https://octopart.com/opatz8j6/a1 | 41966 | 0.0124 | 21 | 0.2604 | GRM152R60J104KE19D | Murata | Cut Tape | 1 | 1 | €16.45 (qty: 2100) | GRM152R60J104KE19D |  | 490-14871-1-ND |  | 81-GRM152R60J104KE9D |  |  | Not Recommended for New Designs | Compliant | Yes | Ciiva Crawler: https://datasheet.octopart.com/GRM152R60J104KE19D-Murata-datasheet-140678630.pdf | 16.45 | 41966
GRM155R60J474KE19D | Murata | C79, C80, C81, C82, C83, C84, C85, C86, C87, C89, C90, C91, C92, C100, C102, C103, C107, C118 | 18 | Exact | 0402 0.47 uF 6.3 V ±10% Tolerance X5R SMT Multilayer Ceramic Capacitor | Mouser 81-GRM155R60J474KE9D (https://octopart.com/opatz8j6/a1) | Mouser | 81-GRM155R60J474KE9D (https://octopart.com/opatz8j6/a1) | https://octopart.com/opatz8j6/a1 | 47097 | 0.056 | 18 | 1.01 | GRM155R60J474KE19D | Murata | Cut Tape | 1 |  | €37.15 (qty: 1800) | GRM155R60J474KE19D | GRM155R60J474KE19D | 490-3266-1-ND | 4266862 | 81-GRM155R60J474KE9D | 94AK6858 |  | Not Recommended for New Designs | Compliant | Yes | Octopart: https://datasheet.octopart.com/GRM155R60J474KE19D-Murata-datasheet-12515295.pdf | 37.15 | 4681874
GRM155R60J103KA01D | Murata | C104, C106, C108, C110, C111, C112, C113, C114, C115, C116, C119, C121, C123, C124 | 14 | Exact | 0402 10 nF 6.3V ±10% Tolerance X5R SMT Multilayer Ceramic Capacitor | DigiKey 490-6286-1-ND (https://octopart.com/opatz8j6/a1) | DigiKey | 490-6286-1-ND (https://octopart.com/opatz8j6/a1) | https://octopart.com/opatz8j6/a1 | 6298 | 0.025 | 14 | 0.35 | GRM155R60J103KA01D | Murata | Cut Tape | 1 |  | €11.23 (qty: 1400) | GRM155R60J103KA01D |  | 490-6286-1-ND |  | 81-GRM155R60J103KA1D | 97AK4032 |  | Not Recommended for New Designs | Compliant | Yes | Future Electronics: https://datasheet.octopart.com/GRM155R60J103KA01D-Murata-datasheet-14400488.pdf | 11.23 | 58257
GCM188R72A223KA37J | Murata | C48, C49, C50, C51, C52, C53 | 6 | Exact | Ceramic Capacitor, Ceramic, 100V, 10% +Tol, 10% -Tol, X7R, 15% TC, 0.022uF, Surface Mount, 0603 | Newark 66AJ7159 (https://octopart.com/opatz8j6/a1) | Newark | 66AJ7159 (https://octopart.com/opatz8j6/a1) | https://octopart.com/opatz8j6/a1 | 14201 | 0.035 | 10 | 0.35 | GCM188R72A223KA37J | Murata | Cut Tape | 1 | 1 | €4.10 (qty: 600) | GCM188R72A223KA37J | GCM188R72A223KA37J | 490-17777-1-ND | 5139968 | 81-GCM188R72A223KA7J | 66AJ7159 |  | Active | Compliant | Yes | Newark: https://datasheet.octopart.com/GCM188R72A223KA37J-Murata-datasheet-155345028.pdf | 4.1 | 29893
GRM188R60J226MEA0J | Murata | C1, C3, C4, C5, C7, C8, C9, C11, C12, C76, C95, C96 | 12 | Exact | 0603 6.3 V 22 uF ±20% Tolerance X5R SMT Multilayer Ceramic Chip Capacitor | Mouser 81-GRM188R60J226ME0J (https://octopart.com/opatz8j6/a1) | Mouser | 81-GRM188R60J226ME0J (https://octopart.com/opatz8j6/a1) | https://octopart.com/opatz8j6/a1 | 335152 | 0.089 | 12 | 1.07 | GRM188R60J226MEA0J | Murata |  | 20 | 20 | €15.48 (qty: 1200) | GRM188R60J226MEA0J | GRM188R60J226MEA0J | 490-GRM188R60J226MEA0JCT-ND |  | 81-GRM188R60J226ME0J | 66AJ7192 | 2478053 | Active | Compliant | Yes | Newark: https://datasheet.octopart.com/GRM188R60J226MEA0J-Murata-datasheet-155345068.pdf | 15.48 | 6180
GRM185R60J225KE26J | Murata | C16, C17, C19, C20, C22, C23, C24, C38, C54, C97, C98 | 11 | Exact | Ceramic Capacitor, Multilayer, Ceramic, 6.3V, 10% +Tol, 10% -Tol, X5R, 15% TC, 2.2uF, Surface Mount, 0603 | Mouser 81-GRM185R60J225KE6J (https://octopart.com/opatz8j6/a1) | Mouser | 81-GRM185R60J225KE6J (https://octopart.com/opatz8j6/a1) | https://octopart.com/opatz8j6/a1 | 16504 | 0.123 | 11 | 1.35 | GRM185R60J225KE26J | Murata | Cut Tape | 1 |  | €43.38 (qty: 1100) |  |  | 490-6371-1-ND |  | 81-GRM185R60J225KE6J |  |  | Not Recommended for New Designs | Compliant | Yes | Ciiva Crawler: https://datasheet.octopart.com/GRM185R60J225KE26J-Murata-datasheet-141274232.pdf | 43.38 | 30510
GRM155R60J475ME87J | Murata | C99, C105, C109, C117, C120 | 5 | Exact | Ceramic Capacitor, Ceramic, 6.3V, 20% +Tol, 20% -Tol, X5R, 15% TC, 4.7uF, Surface Mount, 0402 | Newark 66AJ7184 (https://octopart.com/opatz8j6/a1) | Newark | 66AJ7184 (https://octopart.com/opatz8j6/a1) | https://octopart.com/opatz8j6/a1 | 16039 | 0.037 | 10 | 0.37 | GRM155R60J475ME87J | Murata | Tape & Reel | 1 |  | €13.67 (qty: 500) | GRM155R60J475ME87J |  | 490-18211-1-ND |  | 81-GRM155R60J475ME8J | 66AJ7184 | 2608762 | Active | Compliant | Yes | Newark: https://datasheet.octopart.com/GRM155R60J475ME87J-Murata-datasheet-155345052.pdf | 13.67 | 247862
04026C101KAT2A | KYOCERA AVX | C2, C6, C10, C77 | 4 | Exact | 0402 100 pF 6.3 V ±10 % Tolerance X7R Surface Mount Multilayer Ceramic Capacitor | Mouser 581-04026C101KAT2A (https://octopart.com/opatz8j6/a1) | Mouser | 581-04026C101KAT2A (https://octopart.com/opatz8j6/a1) | https://octopart.com/opatz8j6/a1 | 23985 | 0.21 | 4 | 0.84 | 04026C101KAT2A | KYOCERA AVX | Tape & Reel | 1 |  | €25.87 (qty: 400) |  | KGM05AR70J101KH |  |  | 581-04026C101KAT2A |  |  | Active | Compliant | Yes | IHS: https://datasheet.octopart.com/04026C101KAT2A-KYOCERA-AVX-datasheet-170560559.pdf | 25.87 | 25210
AC0402JR-07300RL | Yageo | R18, R21, R22, R23, R24, R25, R26, R34, R35, R36, R37, R38, R40, R41, R42, R43, R44, R45, R46, R47, R70 | 21 | Exact | Res Thick Film 0402 300 Ohm 5% 0.063W(1/16W) ±100ppm/C Pad SMD Automotive T/R | Mouser 603-AC0402JR-07300RL (https://octopart.com/opatz8j6/a1) | Mouser | 603-AC0402JR-07300RL (https://octopart.com/opatz8j6/a1) | https://octopart.com/opatz8j6/a1 | 13936 | 0.007 | 21 | 0.147 | AC0402JR-07300RL | Yageo | Cut Tape | 1 |  | €9.87 (qty: 2100) | AC0402JR-07300RL | 58AK8897 | YAG3540CT-ND |  | 603-AC0402JR-07300RL | 58AK8897 |  | Active | Compliant | Yes | IHS: https://datasheet.octopart.com/AC0402JR-07300RL-Yageo-datasheet-182189377.pdf | 9.87 | 16172
AC0402JR-7W15KL | Yageo | R5, R7, R8, R9, R11, R12, R16, R17, R27, R28, R31, R32, R33, RA1, RA2, RA3, RA4 | 17 | Exact | Chip Resistor Automotive Grade Thick Film 0402 15kOhm 5% Paper T/R | Mouser 603-AC0402JR-7W15KL (https://octopart.com/opatz8j6/a1) | Mouser | 603-AC0402JR-7W15KL (https://octopart.com/opatz8j6/a1) | https://octopart.com/opatz8j6/a1 | 40 | 0.015 | 17 | 0.255 | AC0402JR-7W15KL | Yageo | Tape & Reel | 1 |  | €12.39 (qty: 1700) |  |  |  |  | 603-AC0402JR-7W15KL |  |  | Active | Compliant | Yes | IHS: https://datasheet.octopart.com/AC0402JR-7W15KL-Yageo-datasheet-182189377.pdf | 12.39 | 9990
AC0402JR-074K7L | Yageo | R10, R13, R14, R15, R19, R20, R30, R58, R71 | 10 | Exact | Res Thick Film 0402 4.7K Ohm 5% 0.063W(1/16W) ±100ppm/C Pad SMD Automotive T/R | Newark 82AH6467 (https://octopart.com/opatz8j6/a1) | Newark | 82AH6467 (https://octopart.com/opatz8j6/a1) | https://octopart.com/opatz8j6/a1 | 99 | 0.001 | 10 | 0.01 | AC0402JR-074K7L | Yageo |  | 1 | 1 | €4.56 (qty: 1000) | AC0402JR-074K7L | 49AK0473 | 311-4.7KLBCT-ND |  | 603-AC0402JR-074K7L | 49AK0473 | 1978008 | Active | Compliant | Yes | IHS: https://datasheet.octopart.com/AC0402JR-074K7L-Yageo-datasheet-182189377.pdf | 4.56 | 8750
AC0402JR-7W1KL | Yageo | R4, R6, R29, R68, R69 | 5 | Exact | Res Thick Film 0402 1K Ohm 5% 0.125W(1/8W) ±100ppm/°C Pad SMD T/R Automotive AEC-Q200 | Mouser 603-AC0402JR-7W1KL (https://octopart.com/opatz8j6/a1) | Mouser | 603-AC0402JR-7W1KL (https://octopart.com/opatz8j6/a1) | https://octopart.com/opatz8j6/a1 | 263585 | 0.009 | 10 | 0.09 | AC0402JR-7W1KL | Yageo | Cut Tape | 1 |  | €3.05 (qty: 500) |  |  | 13-AC0402JR-7W1KLCT-ND |  | 603-AC0402JR-7W1KL |  |  | Active | Compliant | Yes | IHS: https://datasheet.octopart.com/AC0402JR-7W1KL-Yageo-datasheet-182189377.pdf | 3.05 | 10054
AC0402JR-0727RL | Yageo | R1, R2 | 2 | Exact | AC Series 0402 27 Ohm ±5% 0.063 W ±200 ppm/°C Thick Film Chip Resistor | Mouser 603-AC0402JR-0727RL (https://octopart.com/opatz8j6/a1) | Mouser | 603-AC0402JR-0727RL (https://octopart.com/opatz8j6/a1) | https://octopart.com/opatz8j6/a1 | 39545 | 0.007 | 10 | 0.07 | AC0402JR-0727RL | Yageo | Cut Tape | 1 |  | €1.12 (qty: 200) |  | 58AK8894 | 13-AC0402JR-0727RLCT-ND |  | 603-AC0402JR-0727RL | 58AK8894 |  | Active | Compliant | Yes | IHS: http://datasheet.octopart.com/AC0402JR-0727RL-Yageo-datasheet-182189377.pdf | 1.12 | 52516
AC0402JR-073K3L | Yageo | RB3 | 1 | Exact | Res Thick Film 0402 3.3K Ohm 5% 0.063W(1/16W) ±100ppm/C Pad SMD T/R Automotive AEC-Q200 | Arrow Electronics AC0402JR-073K3L (https://octopart.com/opatz8j6/a1) | Arrow Electronics | AC0402JR-073K3L (https://octopart.com/opatz8j6/a1) | https://octopart.com/opatz8j6/a1 | 15198 | 0.016 | 1 | 0.016 | AC0402JR-073K3L | Yageo | Cut Tape | 1 | 1 | €0.24597 (qty: 100) | AC0402JR-073K3L | 59AK5032 | YAG3544CT-ND | 5110652 | 603-AC0402JR-073K3L | 59AK5032 |  | Active | Compliant | Yes | IHS: https://datasheet.octopart.com/AC0402JR-073K3L-Yageo-datasheet-182189377.pdf | 0.24597 | 15198
AC0402JR-0712KL | Yageo | RB4 | 1 | Exact | Res Thick Film 0402 12K Ohm 5% 0.063W(1/16W) ±100ppm/C Pad SMD T/R Automotive AEC-Q200 | Arrow Electronics AC0402JR-0712KL (https://octopart.com/opatz8j6/a1) | Arrow Electronics | AC0402JR-0712KL (https://octopart.com/opatz8j6/a1) | https://octopart.com/opatz8j6/a1 | 8331 | 0.016 | 1 | 0.016 | AC0402JR-0712KL | Yageo | Cut Tape | 1 | 1 | €0.10021 (qty: 100) | AC0402JR-0712KL |  | 13-AC0402JR-0712KLCT-ND |  | 603-AC0402JR-0712KL |  |  | Active | Compliant | Yes | IHS: https://datasheet.octopart.com/AC0402JR-0712KL-Yageo-datasheet-182189377.pdf | 0.10021 | 8331
AC0402JR-0718KL | Yageo | RB1 | 1 | Exact | Res Thick Film 0402 18K Ohm 5% 0.063W(1/16W) ±100ppm/C Pad SMD Automotive T/R | Mouser 603-AC0402JR-0718KL (https://octopart.com/opatz8j6/a1) | Mouser | 603-AC0402JR-0718KL (https://octopart.com/opatz8j6/a1) | https://octopart.com/opatz8j6/a1 | 150000 | 0.007 | 10 | 0.07 | AC0402JR-0718KL | Yageo | Tape & Reel | 1 |  | €0.54660 (qty: 100) | AC0402JR-0718KL |  | 13-AC0402JR-0718KLCT-ND |  | 603-AC0402JR-0718KL |  |  | Active | Compliant | Yes | IHS: http://datasheet.octopart.com/AC0402JR-0718KL-Yageo-datasheet-182189377.pdf | 0.5466 | 20000
AC0402FR-0771R5L | Yageo | R39, R48, R49, R50, R51, R52, R82, R83 | 8 | Exact | Chip Resistor Automotive Grade Thick Film 0402 71.5Ohm 1% Paper T/R | Mouser 603-AC0402FR-0771R5L (https://octopart.com/opatz8j6/a1) | Mouser | 603-AC0402FR-0771R5L (https://octopart.com/opatz8j6/a1) | https://octopart.com/opatz8j6/a1 | 29310 | 0.014 | 10 | 0.14 | AC0402FR-0771R5L | Yageo | Tape & Reel | 1 |  | €6.56 (qty: 800) |  |  | 13-AC0402FR-0771R5LCT-ND |  | 603-AC0402FR-0771R5L |  |  | Active | Compliant | Yes | IHS: https://datasheet.octopart.com/AC0402FR-0771R5L-Yageo-datasheet-182189377.pdf | 6.56 | 29460
RC0402FR-0712R1L | Yageo | R65 | 1 | Exact | Res Thick Film 0402 12.1 Ohm 1% 1/16W +/-100ppm/ﾟC Molded SMD SMD Paper T/R | Mouser 603-RC0402FR-0712R1L (https://octopart.com/opatz8j6/a1) | Mouser | 603-RC0402FR-0712R1L (https://octopart.com/opatz8j6/a1) | https://octopart.com/opatz8j6/a1 | 247295 | 0.007 | 10 | 0.07 | RC0402FR-0712R1L | Yageo | Cut Tape | 1 |  | €0.600 (qty: 100) | RC0402FR-0712R1L |  | YAG2965CT-ND |  | 603-RC0402FR-0712R1L |  |  | Active | Compliant | Yes | IHS: https://datasheet.octopart.com/RC0402FR-0712R1L-Yageo-datasheet-175887523.pdf | 0.6 | 38978
AC0402JR-0791KL | Yageo | RC2 | 1 | Exact | Chip Resistor Automotive Grade Thick Film 0402 91kOhm 5% Paper T/R | Mouser 603-AC0402JR-0791KL (https://octopart.com/opatz8j6/a1) | Mouser | 603-AC0402JR-0791KL (https://octopart.com/opatz8j6/a1) | https://octopart.com/opatz8j6/a1 | 53706 | 0.009 | 10 | 0.09 | AC0402JR-0791KL | Yageo | Cut Tape | 1 | 1 | €0.09110 (qty: 100) |  | 59AK3056 |  |  | 603-AC0402JR-0791KL | 59AK3056 |  | Active | Compliant | Yes | IHS: https://datasheet.octopart.com/AC0402JR-0791KL-Yageo-datasheet-182189377.pdf | 0.0911 | 20000
RT0402FRE0710K2L | Yageo | R72, R73, R74, R75, R76, R77, R84, R85, R86, R87 | 10 | Exact | Fixed Resistor, Thin Film, 0.0625W, 10200ohm, 50V, 1% +/-Tol, 50ppm/Cel, Surface Mount, 0402 | Mouser 603-RT0402FRE0710K2L (https://octopart.com/opatz8j6/a1) | Mouser | 603-RT0402FRE0710K2L (https://octopart.com/opatz8j6/a1) | https://octopart.com/opatz8j6/a1 | 28105 | 0.018 | 10 | 0.18 | RT0402FRE0710K2L | Yageo | Cut Tape | 1 |  | €14.11 (qty: 1000) |  |  | 13-RT0402FRE0710K2LCT-ND |  | 603-RT0402FRE0710K2L |  |  | Active | Compliant | Yes | IHS: https://datasheet.octopart.com/RT0402FRE0710K2L-Yageo-datasheet-176402239.pdf | 14.11 | 17120
RC0402FR-13240RL | Yageo | R81 | 1 | Exact | Res Thick Film 0402 240 Ohm 1% 0.063W(1/16W) ±100ppm/C Pad SMD T/R | Mouser 603-RC0402FR-13240RL (https://octopart.com/opatz8j6/a1) | Mouser | 603-RC0402FR-13240RL (https://octopart.com/opatz8j6/a1) | https://octopart.com/opatz8j6/a1 | 259135 | 0.008 | 10 | 0.08 | RC0402FR-13240RL | Yageo | Cut Tape | 1 |  | €0.700 (qty: 100) |  |  | 13-RC0402FR-13240RLCT-ND |  | 603-RC0402FR-13240RL |  |  | Active | Compliant | Yes | IHS: https://datasheet.octopart.com/RC0402FR-13240RL-Yageo-datasheet-175887523.pdf | 0.7 | 67837
AF0603JR-070RL | Yageo | RV3 | 1 | Exact | Zero Ohm Resistor, Jumper, 0603 [1608 Metric], Ceramic, 100 mW, 1 A, Surface Mount Device | Newark 49AK6954 (https://octopart.com/opatz8j6/a1) | Newark | 49AK6954 (https://octopart.com/opatz8j6/a1) | https://octopart.com/opatz8j6/a1 | 4854 | 0.005 | 1 | 0.005 | AF0603JR-070RL | Yageo | Cut Tape | 1 | 1 | €0.45550 (qty: 100) | AF0603JR-070RL | 49AK6954 | 13-AF0603JR-070RLCT-ND |  | 603-AF0603JR-070RL | 49AK6954 |  | Active | Compliant | Yes | IHS: https://datasheet.octopart.com/AF0603JR-070RL-Yageo-datasheet-182189397.pdf | 0.4555 | 4854

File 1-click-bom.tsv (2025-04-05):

References | Qty | Description | Manufacturer | MPN | Manufacturer | MPN | Manufacturer | MPN | Manufacturer | MPN | Digikey | Mouser | RS | Newark | Farnell | LCSC | JLC Assembly
C2, C6, C10 | 3 | 100pF |  | 04026C101KAT2A | AVX | 04026C101KAT2A |  |  |  |  | 478-12647-6-ND | 58104026C101KAT2A
C25, C26, C27, C28, C29, C30, C31, C32, C33, C34, C35, C55, C56, C57, C58, C59, C61, C62, C63, C64, C65, C66, C67, C68, C69, C70, C71, C72, C73, C74, C75 | 31 | 22nF |  | 04023D223KAT2A | KYOCERA AVX | 04023D223KAT2A |  |  |  |  | 478-10083-1-ND | 58104023D223KAT2A |  |  | 3288826
C48, C49, C50, C51, C52, C53 | 6 | 22nF |  | 06033D223KAT2A | KYOCERA AVX | 06033D223KAT2A |  |  |  |  | 478-06033D223KAT2ATR-ND | 58106033D223KAT2A
C13, C14, C15, C18, C21, C36, C37, C38, C39, C40, C41, C42, C43, C44, C45, C54 | 16 | 100n |  | 0402YD104KAT2A | AVX | 0402YD104KAT2A |  |  |  |  | 478-1126-1-ND | 5810402YD104K | 6983197 |  | 1327666
C60 | 1 | 220nF |  | CGB2T3X5R0J224M022BB | TDK | CGB2T3X5R0J224M022BB |  |  |  |  | 445-15613-1-ND | 810CGB2T3X5R0J224MB
C16, C17, C19, C20, C22, C23, C24, C46, C47 | 9 | 2.2uF |  | 06033D225KAT2A | AVX | 06033D225KAT2A |  |  |  |  |  | 58106033D225KAT2A
C1, C3, C4, C5, C7, C8, C9, C11, C12 | 9 | 22uF |  | C0603C226M9PACTU | KEMET | C0603C226M9PACTU |  |  |  |  |  | 80C0603C226M9PACTU |  |  | 3754565
RV3 | 1 | 0 |  | RC0805JR-070RL | Yageo | RC0805JR-070RL | Yageo | RC0805JR-070RP | Vishay | RCG08050000Z0EA | 311-0.0ARCT-ND | 603RC0805JR070RL | 1995753 |  | 1799478
R1, R2 | 2 | 27 |  | RC0402FR-0727RL | Yageo | RC0402FR-0727RL |  |  |  |  | YAG3086DKR-ND | 603RC0402FR0727RL |  |  | 9239049
R18 | 1 | 130 |  | RC0402FR-07130RL | Yageo | RC0402FR-07130RL |  |  |  |  | 311-130LRDKR-ND | 603RC0402FR07130RL |  |  | 3495526
R41, R42, R43, R44 | 4 | 549 |  | RT0402BRD07549RL | Yageo | RT0402BRD07549RL |  |  |  |  | YAG4280DKR-ND | 603RT0402BRD07549RL
R29, R4, R6 | 3 | 1.1k |  | RC0402JR-071K1L | Yageo | RC0402JR-071K1L |  |  |  |  | 311-1.1KJRCT-ND | 603RC0402JR071K1L
RB3 | 1 | 3.3k |  | RC0402FR-073K3L | Yageo | RC0402FR-073K3L |  |  |  |  | 311-3.30KLRCT-ND | 603RC0402FR073K3L | 1987781 |  | 2693607
R3, R30, RB2, R10, R13, R14, R15, R19, R20 | 9 | 4.7k |  | RC0402JR-074K7L | Yageo | RC0402JR-074K7L |  |  |  |  | 311-4.7KJRCT-ND | 603RC0402JR074K7L | 1987981 |  | 9232842
R11, R12, R27, R28 | 4 | 10k |  | CRCW040210K0FKTD | Vishay | CRCW040210K0FKTD |  |  |  |  | 541-2955-6-ND | 71CRCW040210K |  |  | 1652741RL
R31, R32, R33, RA1, RA2, RA3, R5, R7 | 8 | 15k |  | RMCF0402FT15K0 | Stackpole Electronics | RMCF0402FT15K0 |  |  |  |  | RMCF0402FT15K0CT-ND
RB1 | 1 | 18k |  | RC0402FR-0718KL | Yageo | RC0402FR-0718KL |  |  |  |  | 311-18.0KLRCT-ND | 603RC0402FR0718KL | 1987675 |  | 9239383
R8, R9, R16, R17 | 4 | 100k |  | RMCF0402JT100K | Stackpole Electronics | RMCF0402JT100K |  |  |  |  | RMCF0402JT100KDKR-ND
L1, L2, L3 | 3 | 2.2uH |  | DFE322512F-2R2M=P2 | Murata | DFE322512F-2R2M=P2 | TDK | TFM322512ALMA2R2MTAA |  |  | 445-TFM322512ALMA2R2MTAADKR-ND | 81DFE322512F2R2MP2 |  | 57AC6667 | 3490850 | C285758
D4, D5, D6, D7, D17, D28, D29 | 7 | 1N914 |  | 1N4148WS | Diotec | 1N4148WS | onsemi | 1N914BWS | Nexperia | BAS316Z | 1N914BWSDKR-ND | 5121N914BWS |  |  | 2453274RL
D8, D9 | 2 | 3.6V |  | BZT52C3V6S | Rectron | BZT52C3V6S | MCC | BZT52C3V6S-TP |  |  | BZT52C3V6S-TPMSCT-ND | 833BZT52C3V6STP
D0 | 1 | GREEN |  | LTST-C190GKT | Lite-On | LTST-C190GKT |  |  |  |  | 160-1183-2-ND | 859LTSTC190GKT | 6920975P
D1 | 1 | BLUE |  | LTST-C190TBKT | Lite-On | LTST-C190TBKT |  |  |  |  | 160-1646-1-ND | 859LTSTC190TBKT | 6920994P
D2 | 1 | GREEN |  | LTST-C190GKT | Lite-On | LTST-C190GKT |  |  |  |  | 160-1183-2-ND | 859LTSTC190GKT | 6920975P
D3 | 1 | BLUE |  | LTST-C190TBKT | Lite-On | LTST-C190TBKT |  |  |  |  | 160-1646-1-ND | 859LTSTC190TBKT | 6920994P
U1 | 1 | LFE5UM-85F-8BG381I |  | LFE5UM-85F-8BG381I | Lattice Semiconductor | LFE5UM-85F-8BG381I |  |  |  |  | LFE5UM-85F-8BG381I-ND | 842LFE5UM85F8BG381I
U2 | 1 | IS42S16320D-6BLI |  | IS42S16320D-6BLI | ISSI | IS42S16320D-6BLI |  |  |  |  | IS42S16320D-6BLI-ND | 870IS42S16320D6BLI
U3, U4, U5 | 3 | TLV62569DBV |  | TLV62569DBVR | Texas Instruments | TLV62569DBVR |  |  |  |  | 296-47360-2-ND | 595TLV62569DBVR |  |  | 3121687
U10 | 1 | W25Q128JVSIM |  | W25Q128JVSIM | Winbond | W25Q128JVSIM |  |  |  |  | W25Q128JVSIM-ND | 454W25Q128JVSIM | 1882648P
Y1 | 1 | FO3HSCBE25.0-T1 |  | FO3HSCBE25.0-T1 | Fox Electronics | FO3HSCBE25.0-T1 |  |  |  |  | 631-1432-1-ND | ASE25.000MHZLCT
SW1, SW2 | 2 | SW_Push |  | R-667903 | Mitsumi | R-667903 |  |  |  |  | 2508-R-667903CT-ND
J1, J2 | 2 | DF40C-100DP-0.4V(51) |  | 798-DF40C100DP0.4V51 | Hirose | DF40C-100DP-0.4V(51) |  |  |  |  | H11614DKR-ND | 798DF40C100DP0.4V51 |  |  | 2427678

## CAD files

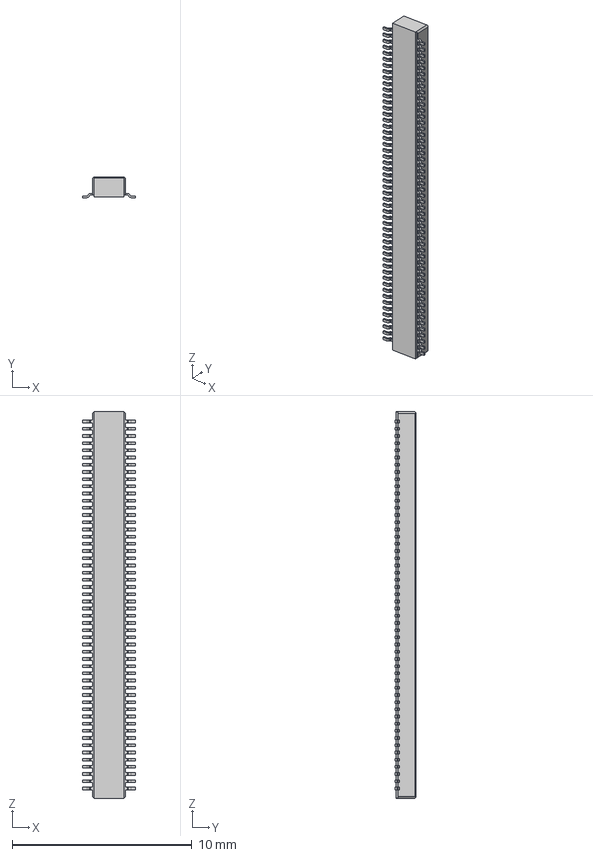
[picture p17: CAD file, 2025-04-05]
footprints/connectors/3D/DF40C-100DP.stp
2.97 x 1.14 x 21.5 mm

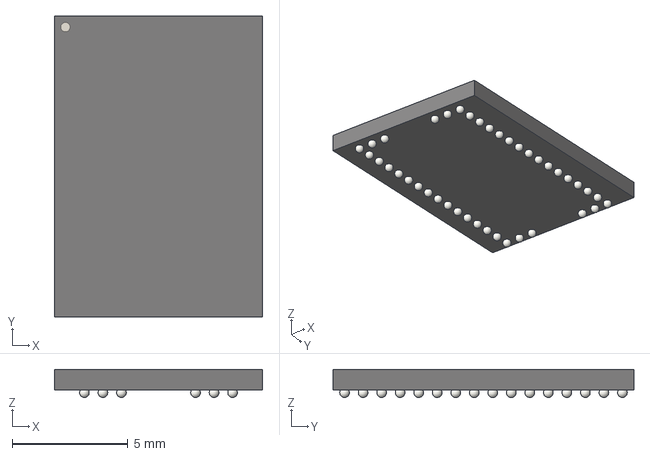
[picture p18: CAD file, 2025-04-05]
footprints/ddr3/AS4C256M16D3/3D/BGA-96_9.0x13.0mm_Layout2x3x16_P0.8mm.step
9.00 x 13.0 x 1.21 mm

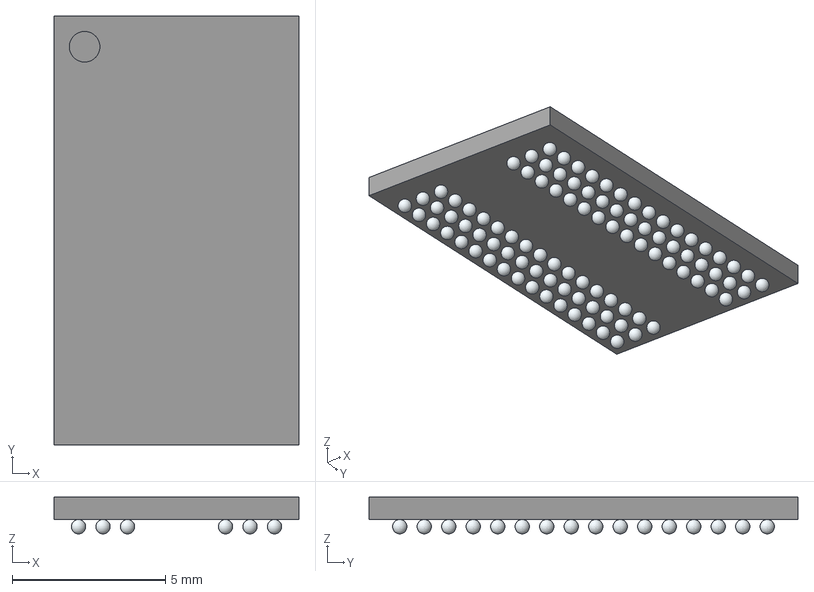
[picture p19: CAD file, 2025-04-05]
footprints/ddr3/MT41K256M16TW-107_P/3D/MT41K256M16TW-107_P.stp
8.00 x 14.0 x 1.20 mm
A1
A2
A3
A7
A8
A9
B1
B2
B3
B7
B8
B9
C1
C2
C3
C7
C8
C9
D1
D2
D3
D7
D8
D9
E1
E2
E3
E7
E8
E9
F1
F2
F3
F7
F8
F9
G1
G2
G3
G7
G8
G9
H1
H2
H3
H7
H8
H9
J1
J2
J3
J7
J8
J9
K1
K2
K3
K7
K8
K9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

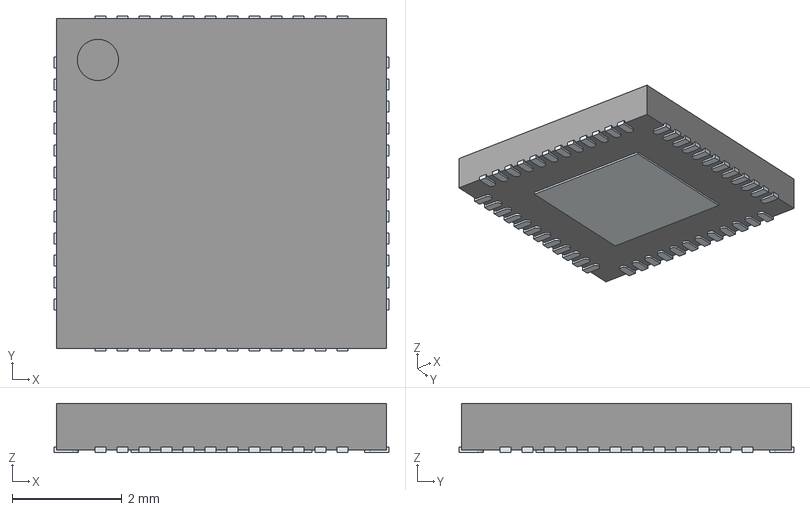
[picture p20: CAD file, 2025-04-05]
footprints/network/VSC8530XMW-04/3D/VSC8530XMW-04.stp
6.10 x 6.10 x 0.9 mm
ThermalPin
PinsArrayLR
PinsArrayTB

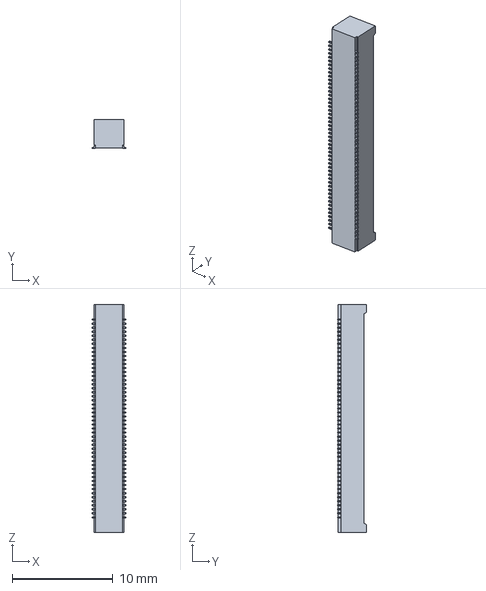
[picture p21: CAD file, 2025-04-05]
footprints/connectors/3D/DF40HC(3.0)-100DS-0.4V.stp
3.38 x 2.90 x 22.6 mm

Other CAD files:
footprints/network/VSC8530XMW-04/3D/VSC8530XMW-04.stl

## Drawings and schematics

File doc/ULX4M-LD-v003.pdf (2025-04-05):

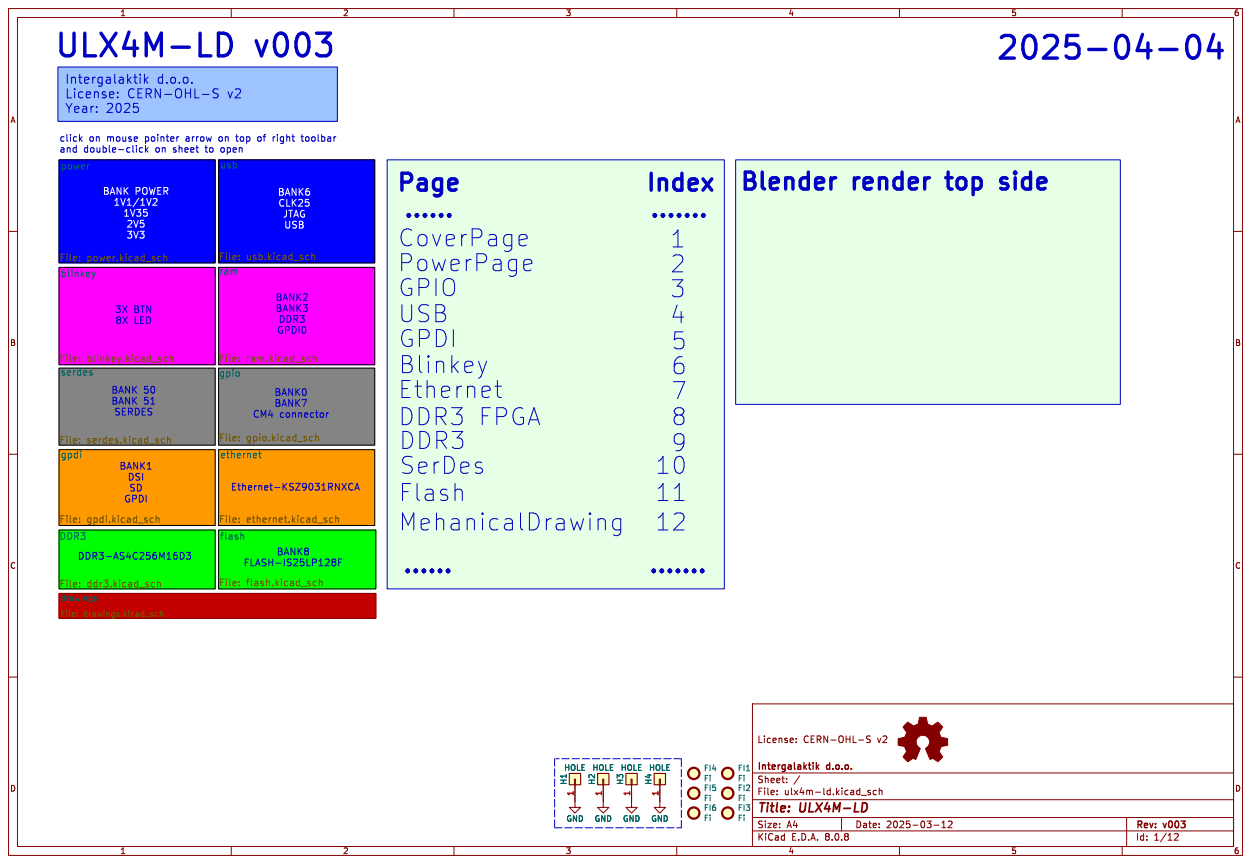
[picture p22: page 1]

3X BTN
GPDI BANK 50 BANK 51 SERDES

serdes File: serdes.kicad_sch
gpio File: gpio.kicad_sch DDR3 File: ddr3.kicad_sch

GND GND GND GND H2 HOLE

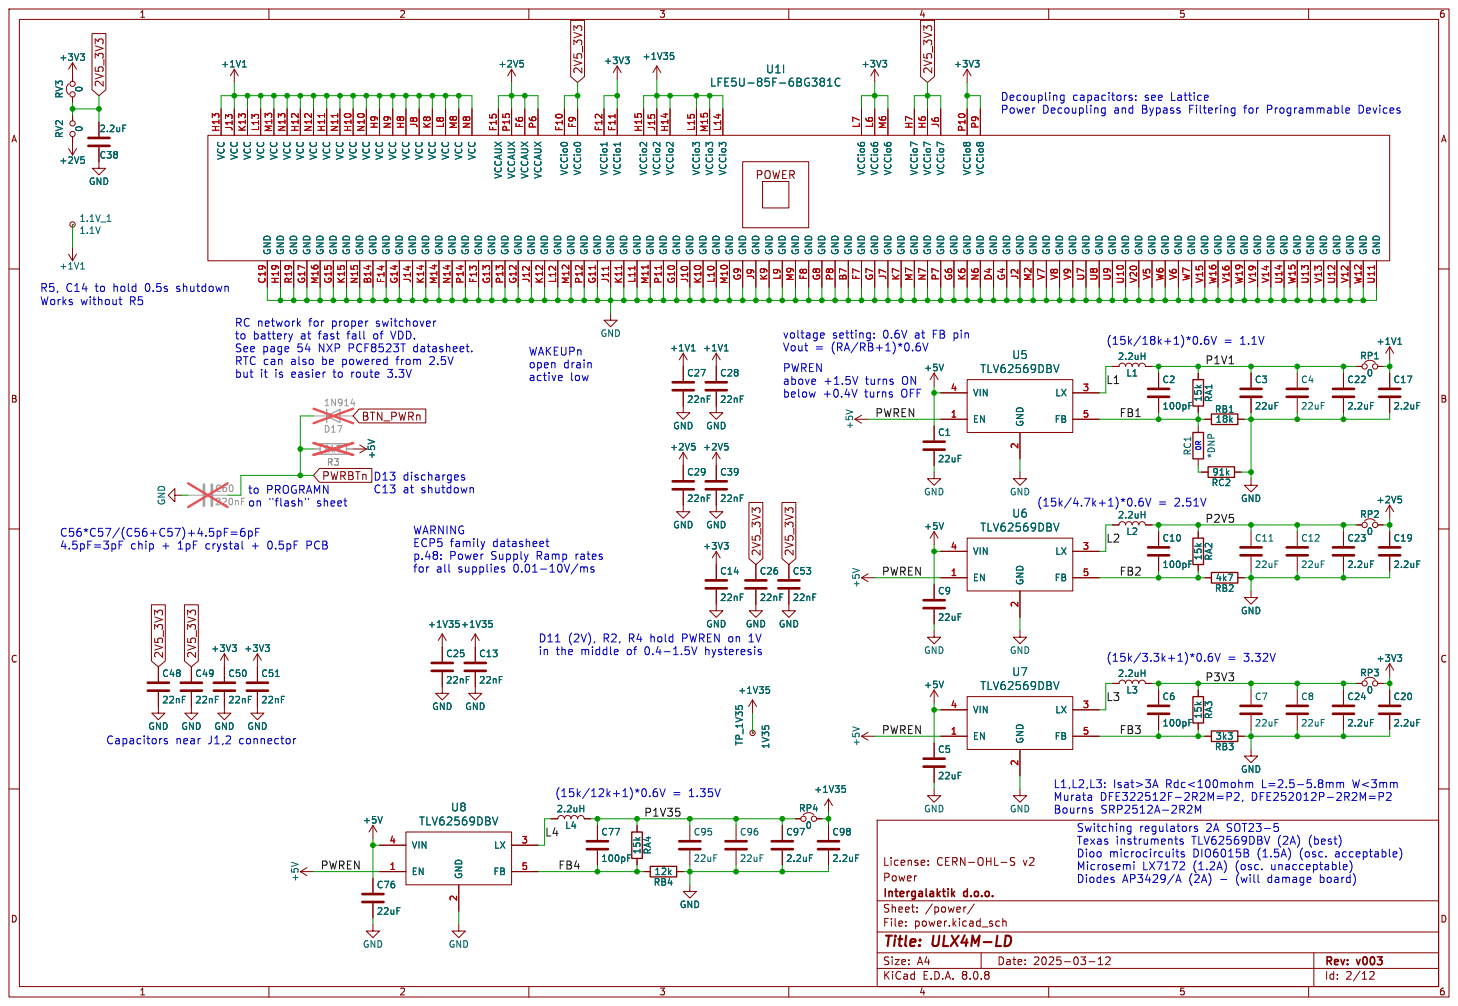
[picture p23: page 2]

RC network for proper switchover
to battery at fast fall of VDD. See page 54 NXP PCF8523T datasheet. RTC can also be powered from 2.5V

voltage setting: 0.6V at FB pin Vout = (RA/RB+1)*0.6V

but it is easier to route 3.3V

ECP5 family datasheet p.48: Power Supply Ramp rates

for all supplies 0.01-10V/ms

File: power.kicad_sch Sheet: /power/
Id: 2/12 Title: ULX4M-LD

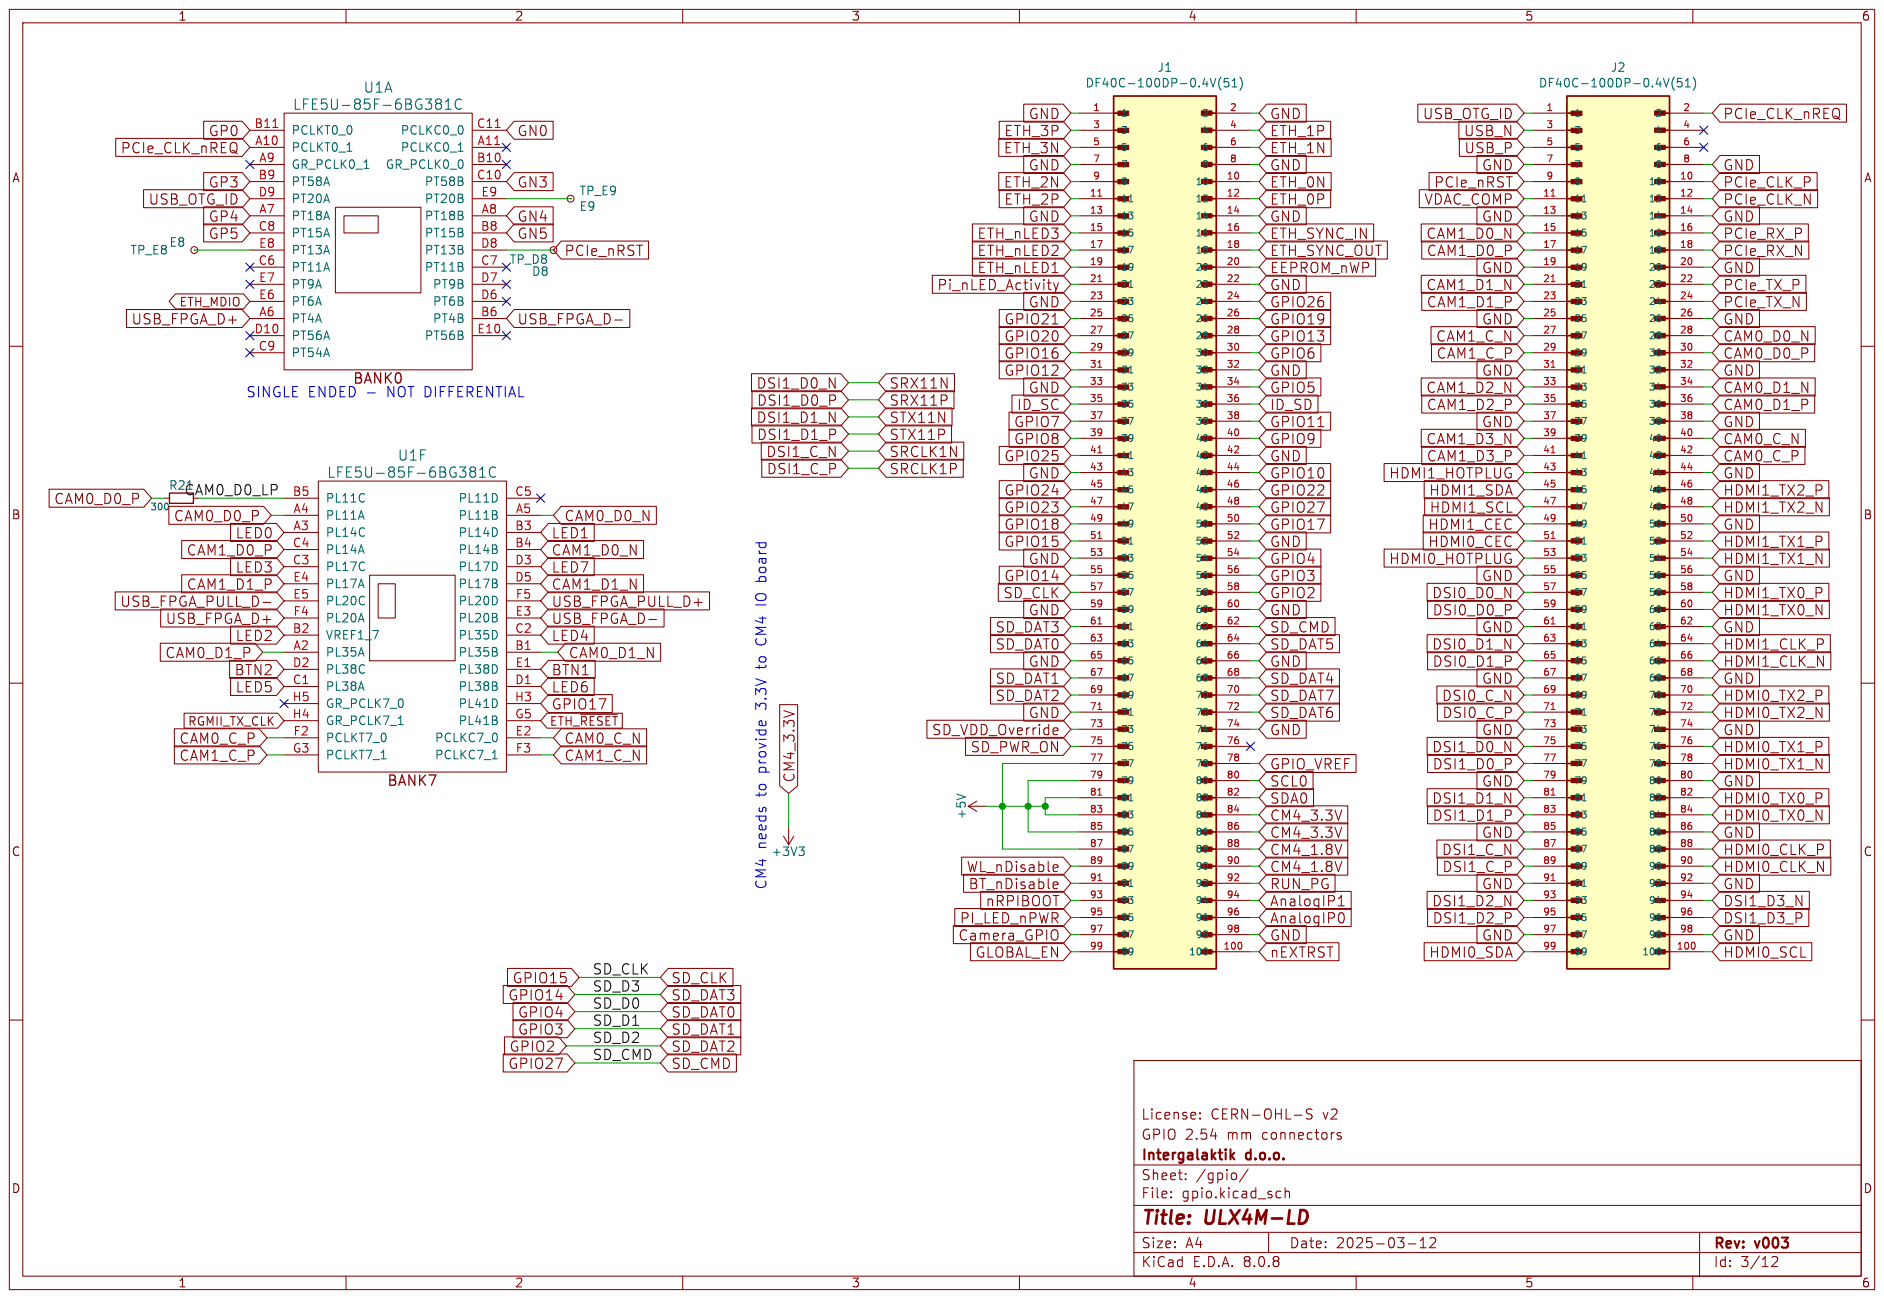
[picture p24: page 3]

SINGLE ENDED - NOT DIFFERENTIAL

File: gpio.kicad_sch Sheet: /gpio/
Id: 3/12 Title: ULX4M-LD

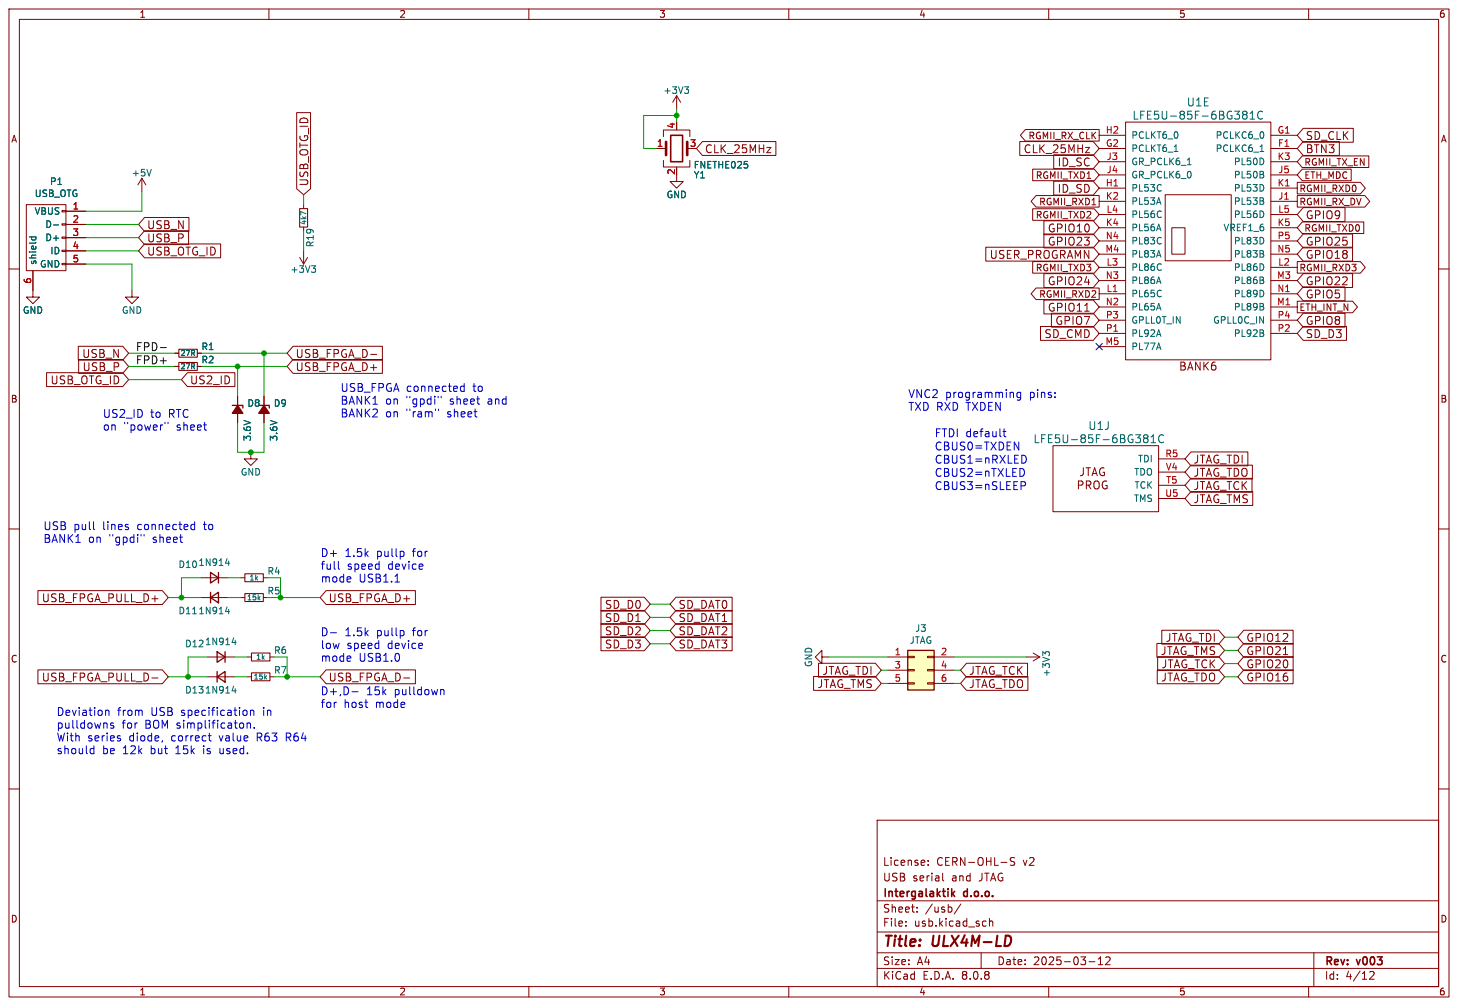
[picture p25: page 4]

D+ 1.5k pullp for
full speed device mode USB1.1

low speed device mode USB1.0

File: usb.kicad_sch Sheet: /usb/
Id: 4/12 Title: ULX4M-LD

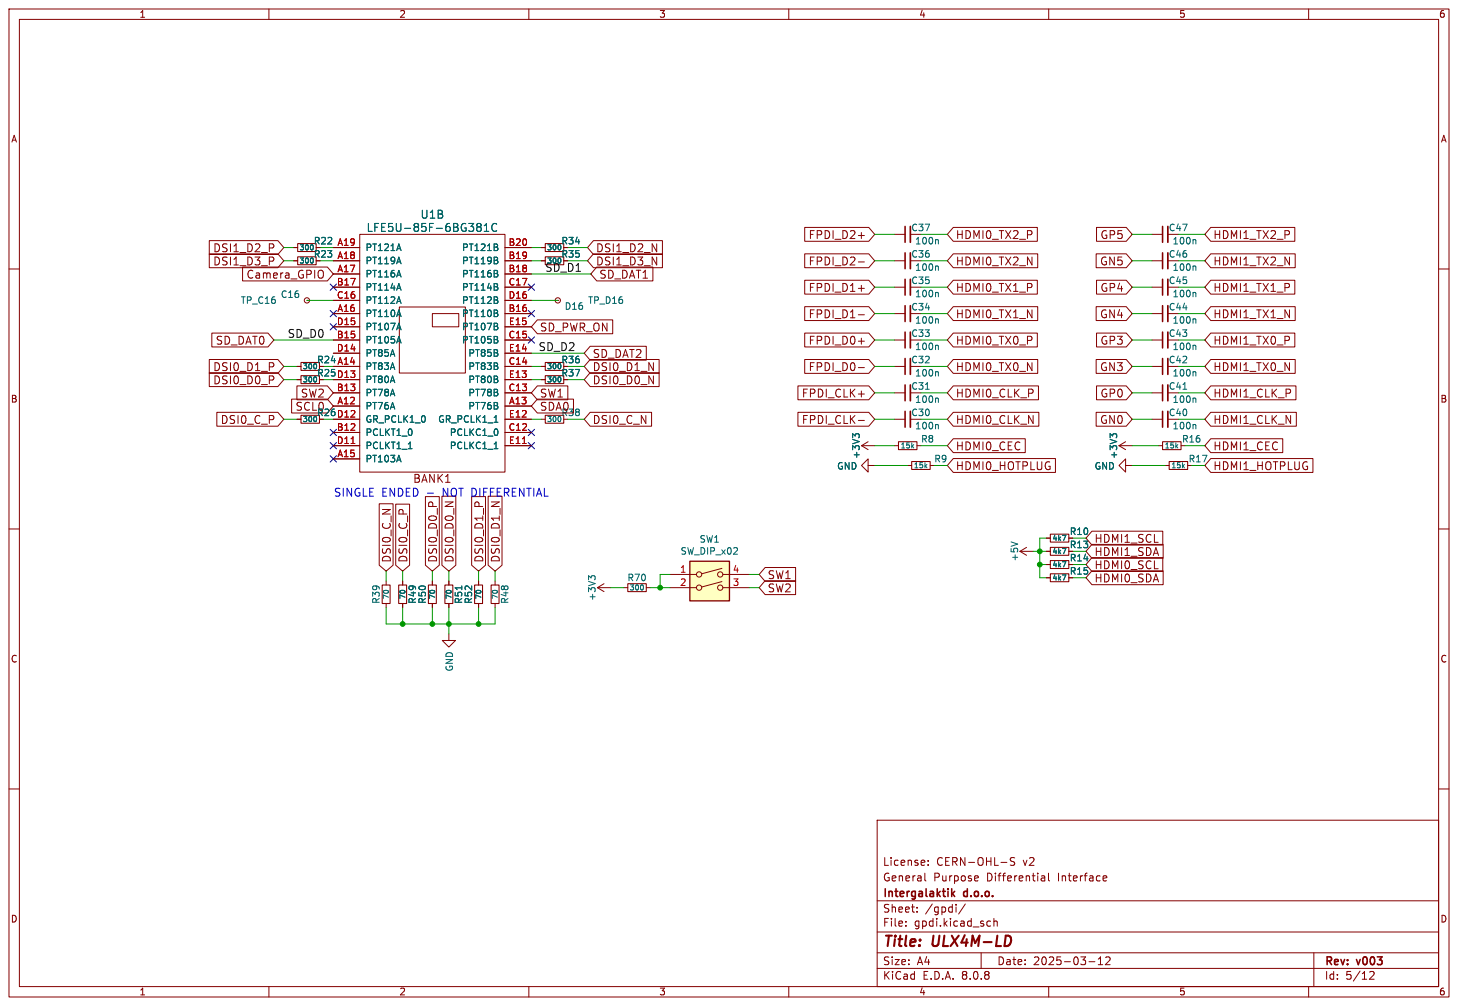
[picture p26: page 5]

SINGLE ENDED - NOT DIFFERENTIAL R26

File: gpdi.kicad_sch Sheet: /gpdi/
Id: 5/12 Title: ULX4M-LD

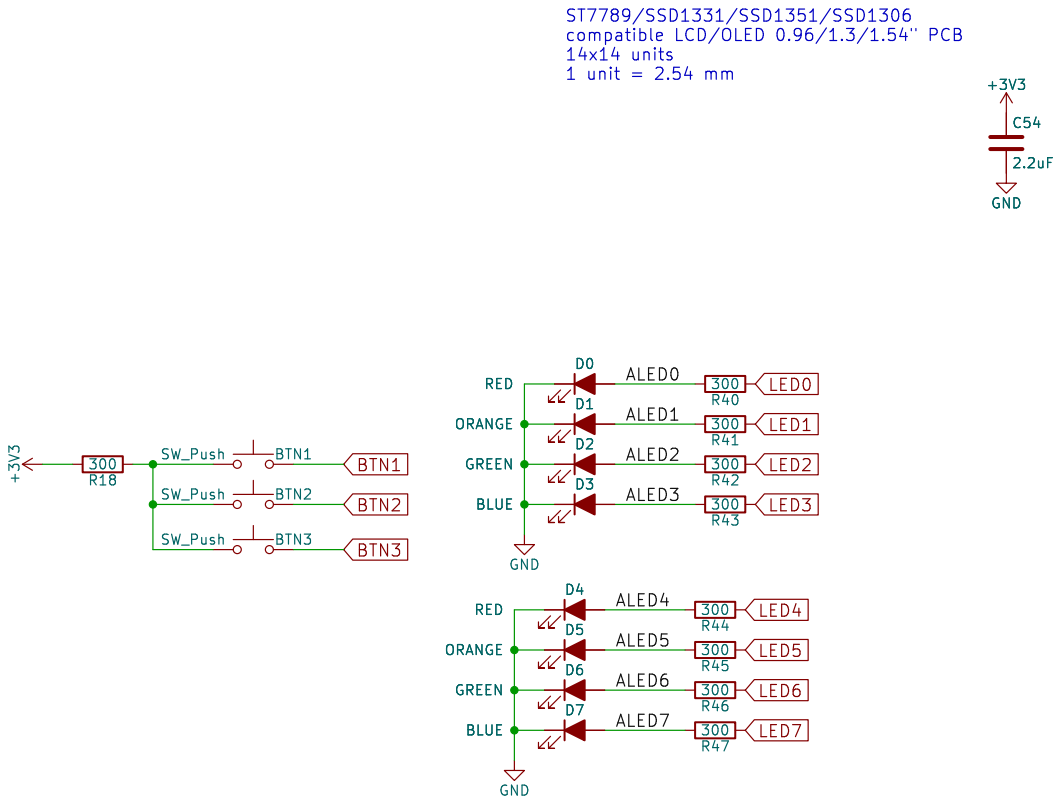
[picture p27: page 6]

File: blinkey.kicad_sch Sheet: /blinkey/
Id: 6/12 Title: ULX4M-LD

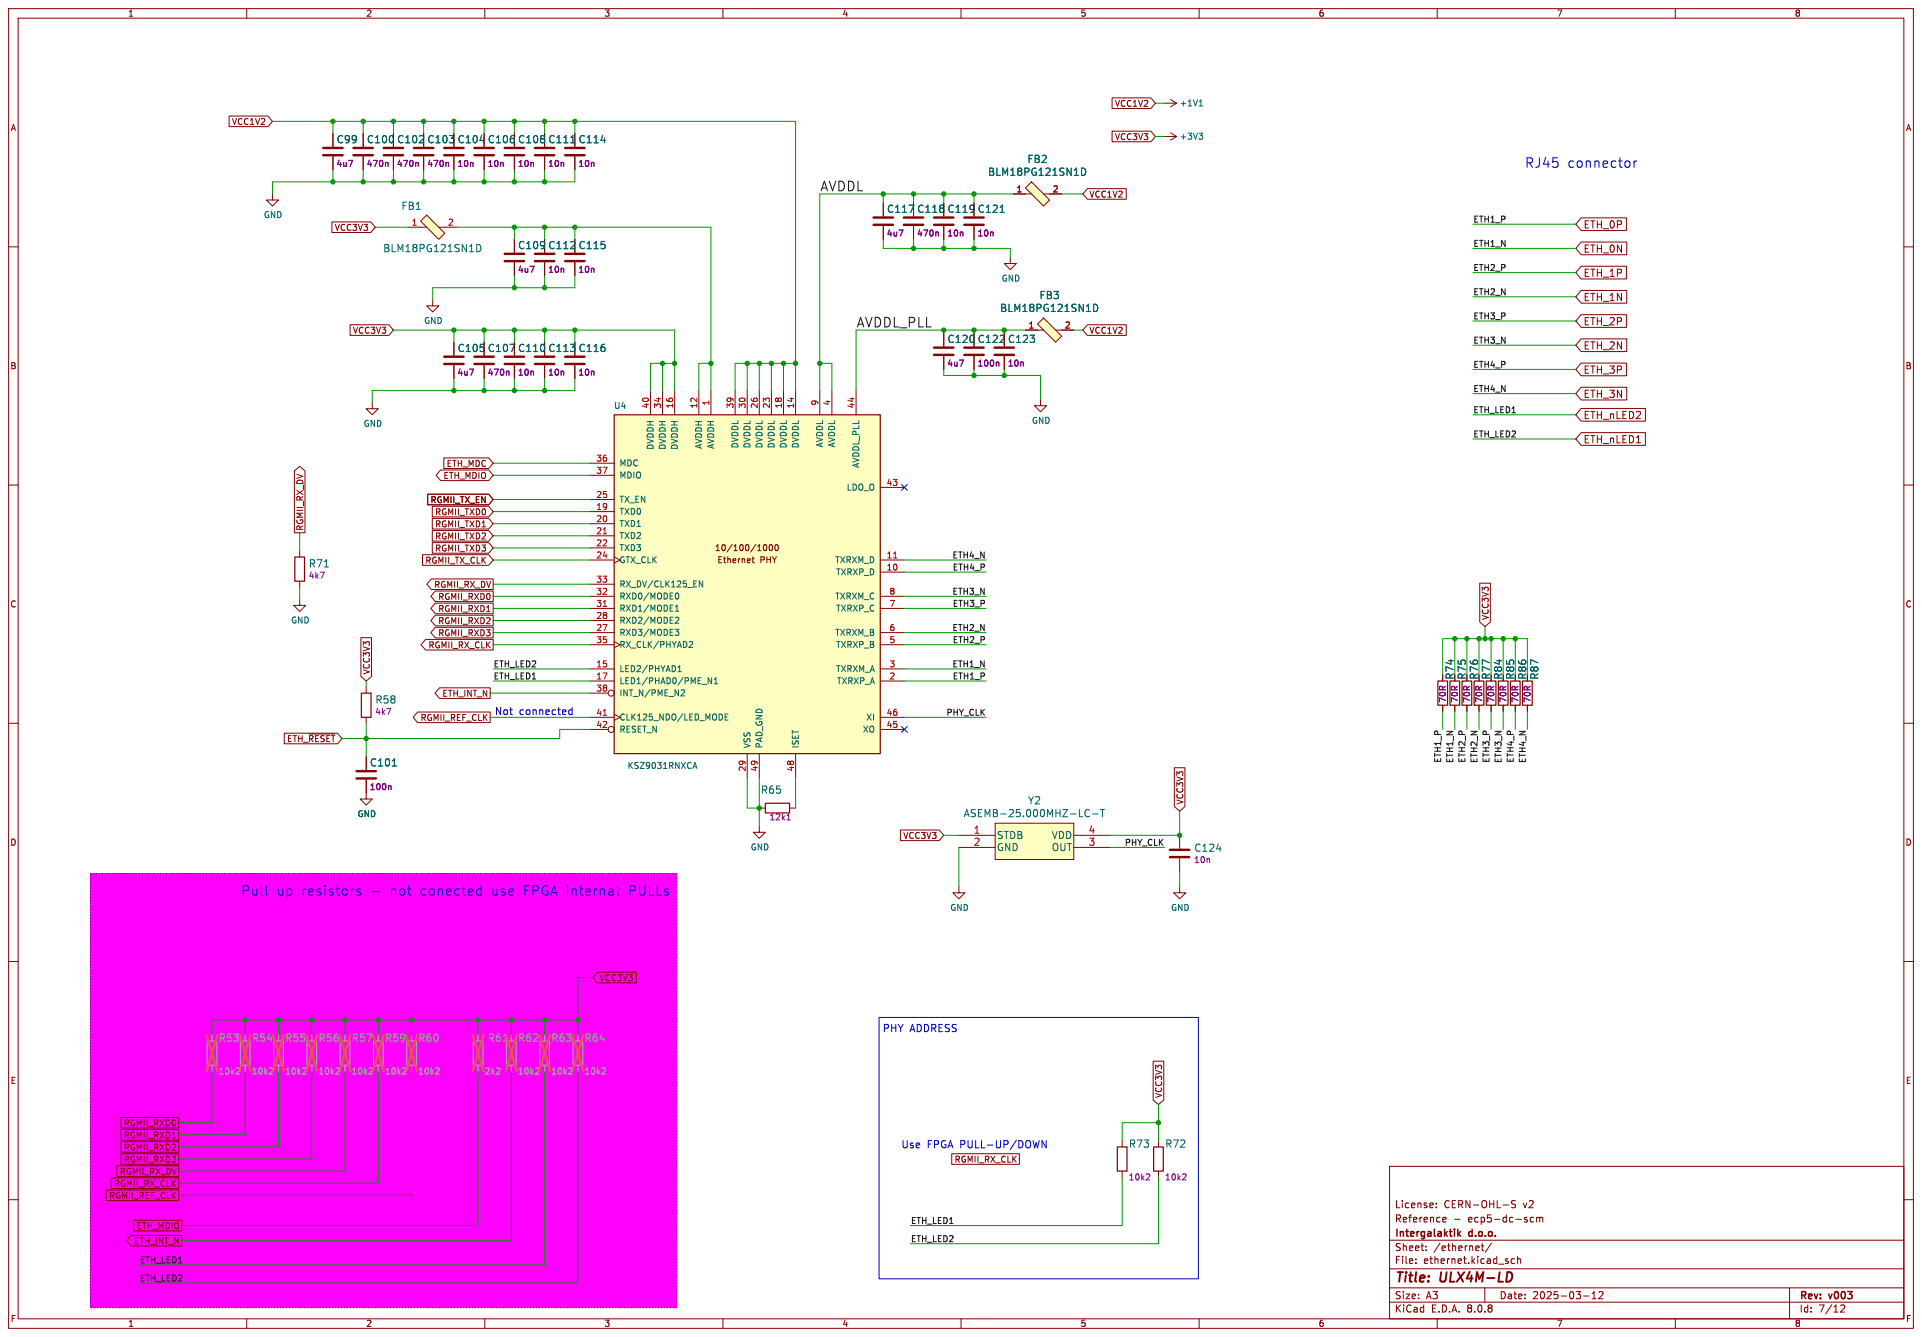
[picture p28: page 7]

9U4 KSZ9031RNXCA STDB 1 GND 2 OUT 3 VDD 4 Y2 ASEMB-25.000MHZ-LC-T R63

PHY ADDRESS Use FPGA PULL-UP/DOWN

File: ethernet.kicad_sch Sheet: /ethernet/
Id: 7/12 Title: ULX4M-LD

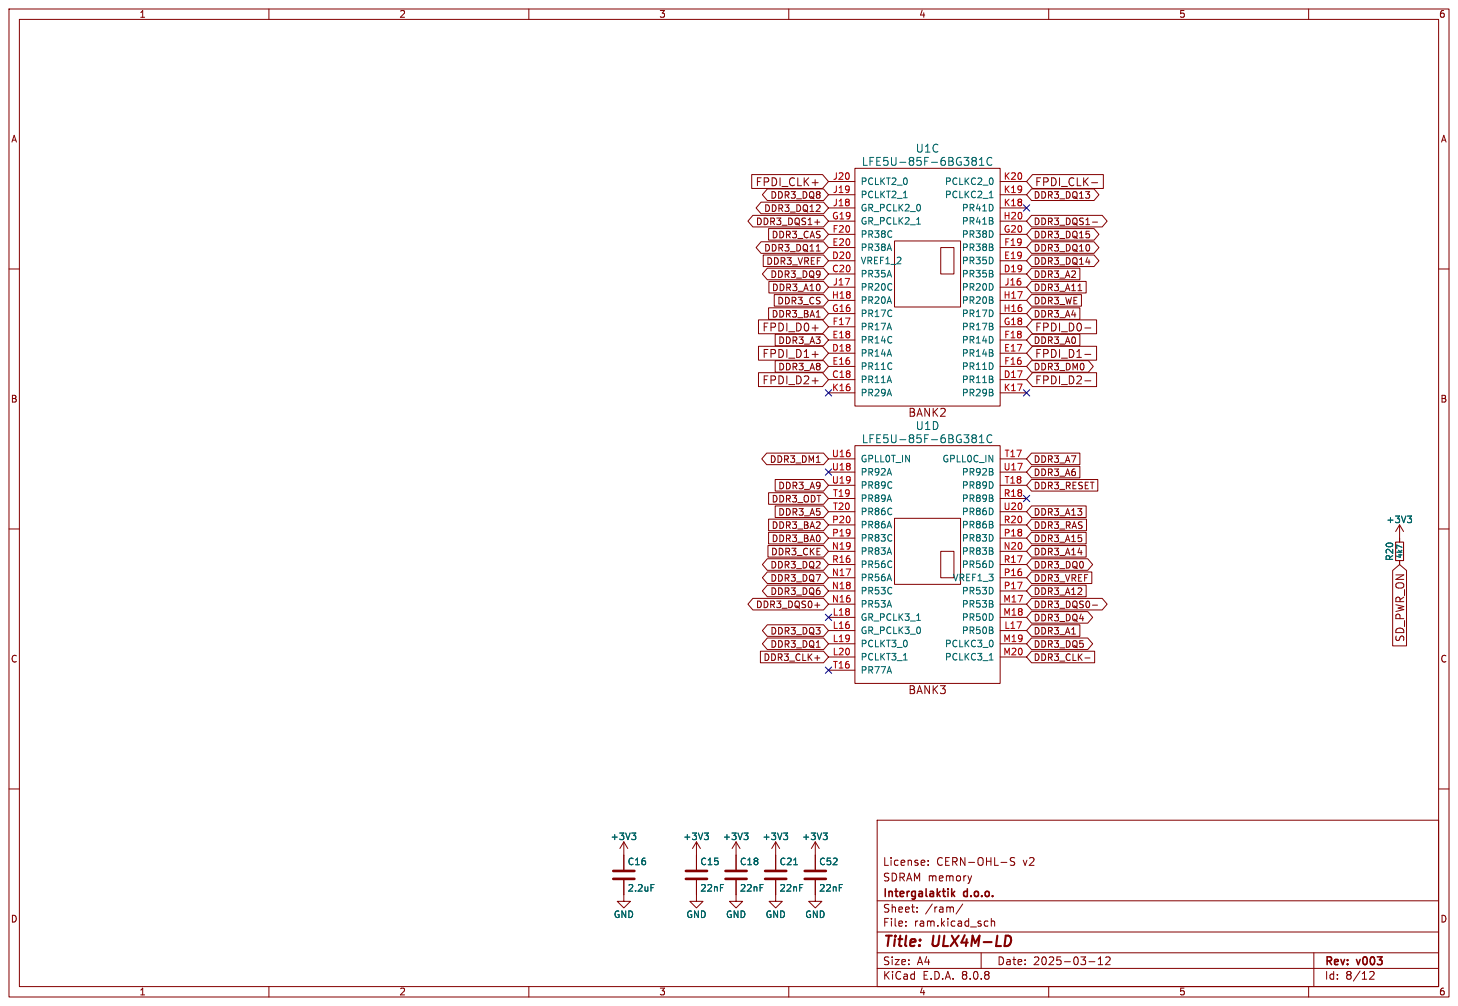
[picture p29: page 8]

File: ram.kicad_sch Sheet: /ram/
Id: 8/12 Title: ULX4M-LD

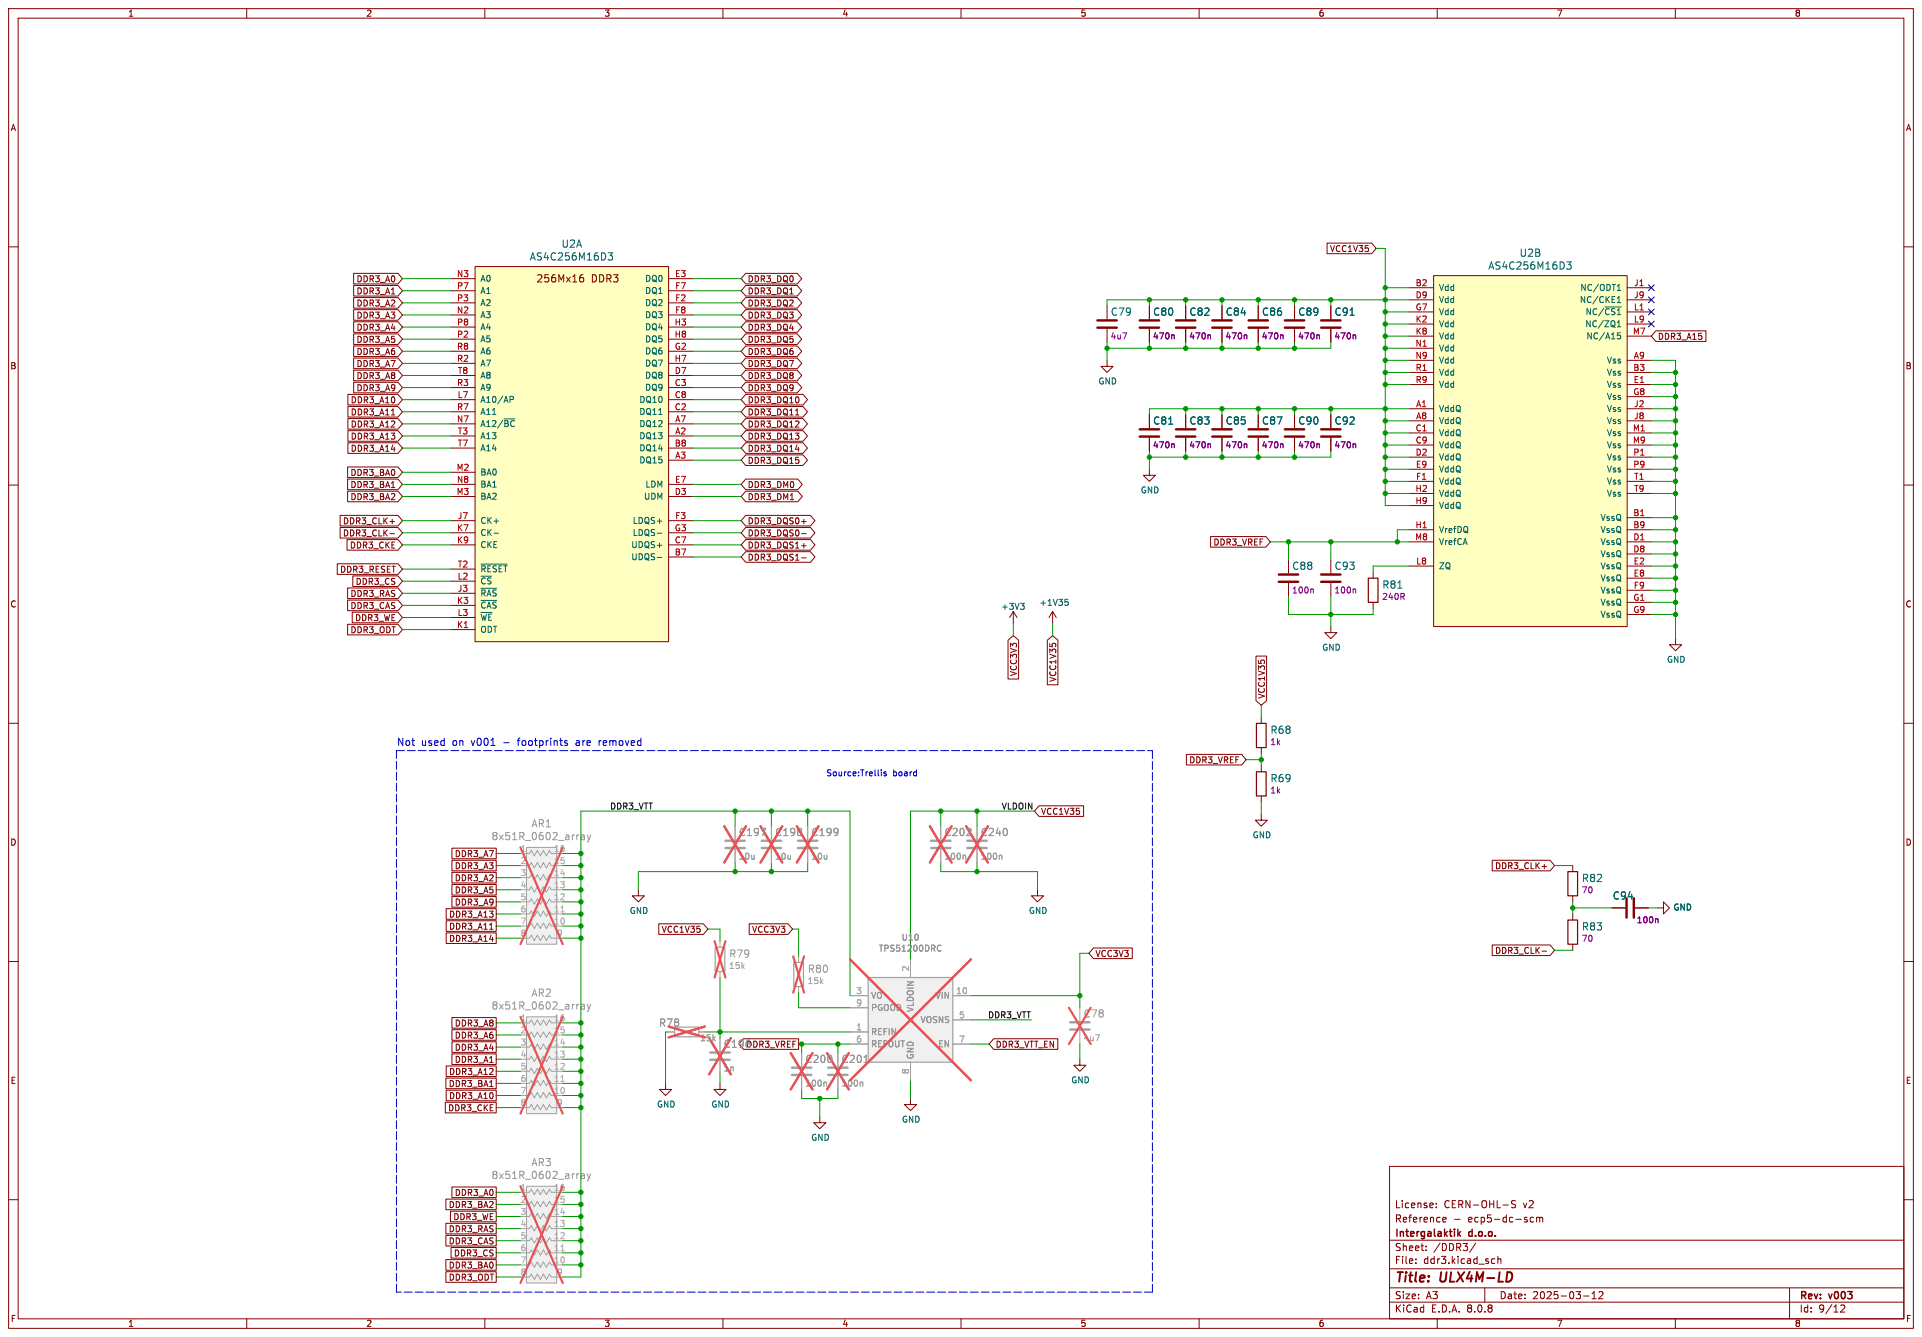
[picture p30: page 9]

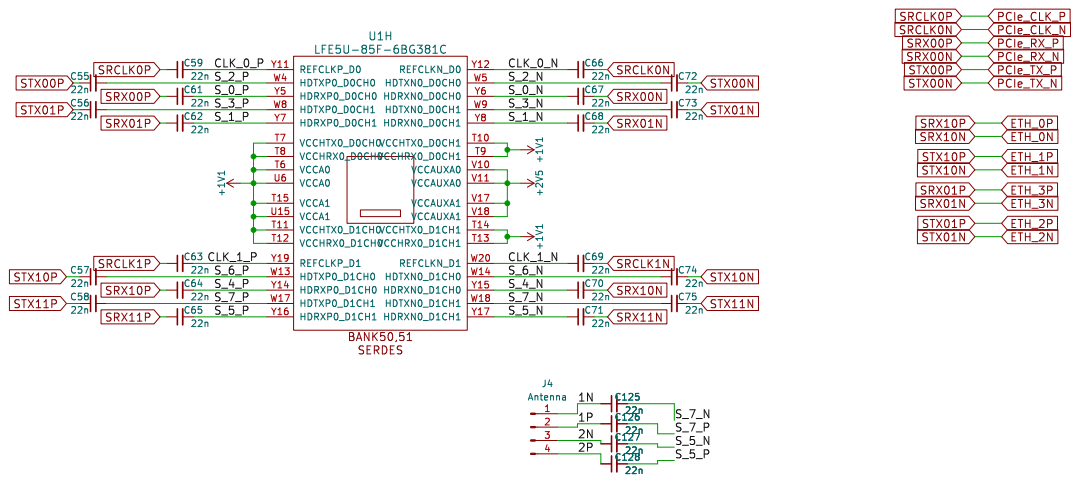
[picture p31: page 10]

File: serdes.kicad_sch Sheet: /serdes/
Id: 10/12 Title: ULX4M-LD

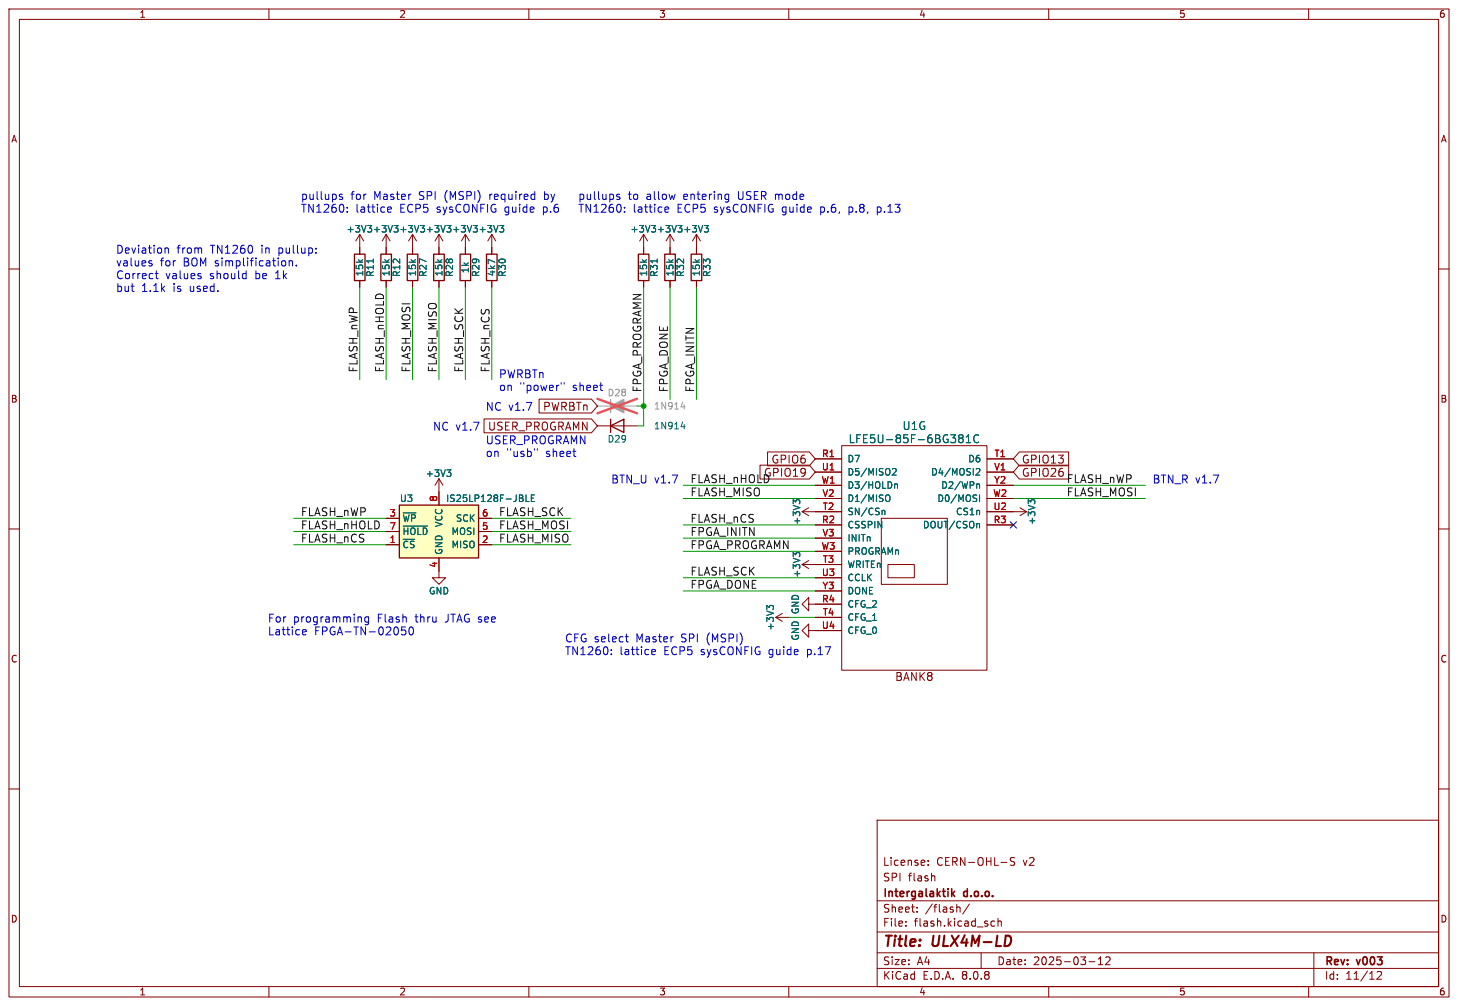
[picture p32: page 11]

on "power" sheet Deviation from TN1260 in pullup: values for BOM simplification.

4 MOSI 5 SCK 6 ~{HOLD} 7 VCC

File: flash.kicad_sch Sheet: /flash/
Id: 11/12 Title: ULX4M-LD

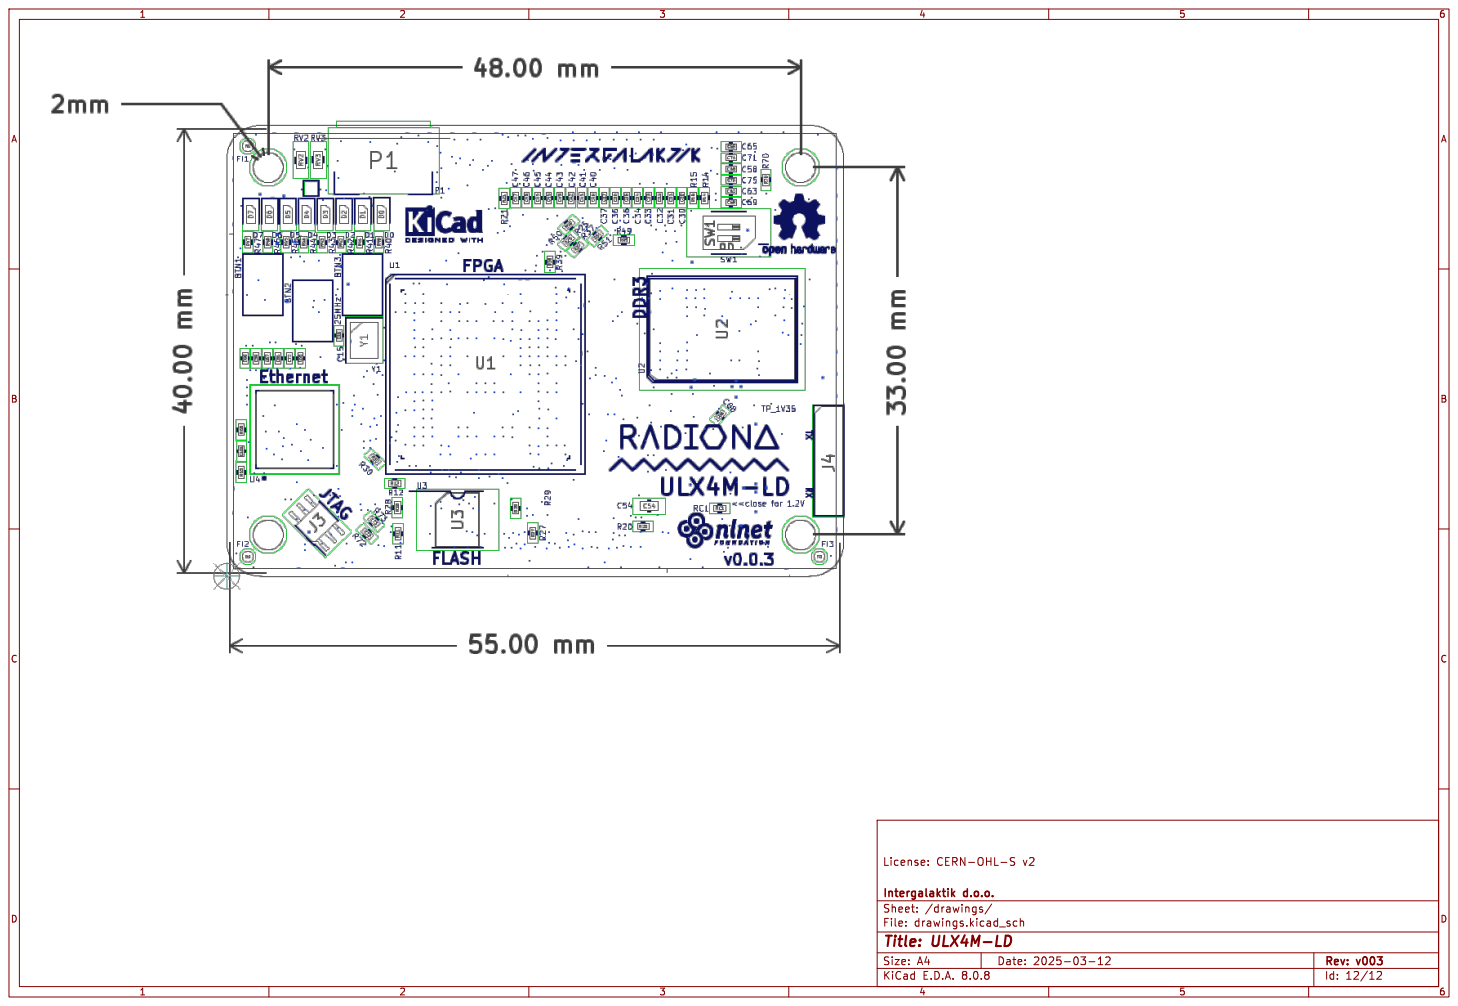
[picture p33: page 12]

File: drawings.kicad_sch Sheet: /drawings/
Id: 12/12 Title: ULX4M-LD

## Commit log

2025-04-05 Initial ULX4M-LD v003
    [1-click-bom.tsv, BGA-96_9.0x13.0mm_Layout2x3x16_P0.8mm.step, DF40C-100DP.stp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]
2025-04-09 Adding BOM - adding DNP to some components
    [ULX4M-LD-v003-2025-BOM.xlsx, power.kicad_sch, serdes.kicad_sch]
2025-08-06 Cleanup of DOC folder
    [ULX4M-LD-v003-2025-BOM.xlsx]

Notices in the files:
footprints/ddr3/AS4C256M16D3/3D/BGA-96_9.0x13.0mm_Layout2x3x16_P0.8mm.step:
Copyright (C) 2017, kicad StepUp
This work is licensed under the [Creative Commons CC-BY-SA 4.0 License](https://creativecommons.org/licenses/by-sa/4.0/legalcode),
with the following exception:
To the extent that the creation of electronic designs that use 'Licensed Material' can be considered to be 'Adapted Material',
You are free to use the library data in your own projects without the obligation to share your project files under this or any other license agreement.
